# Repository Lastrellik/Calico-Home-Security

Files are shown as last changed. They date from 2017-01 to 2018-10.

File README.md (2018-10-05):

Calico Home Security
====================

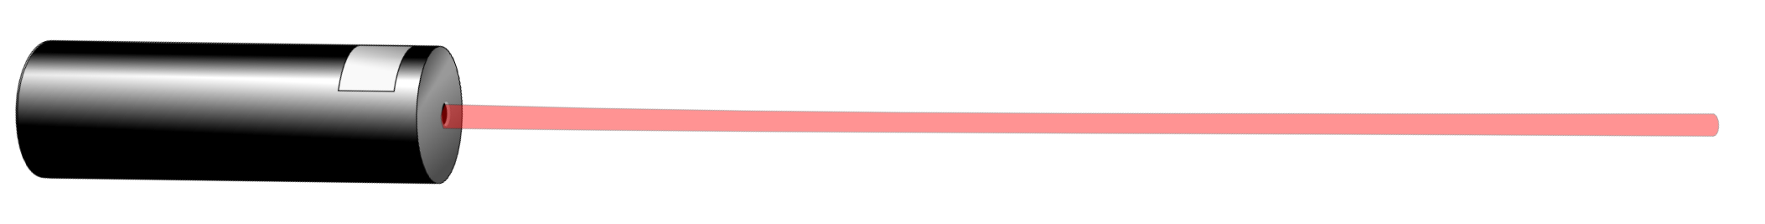
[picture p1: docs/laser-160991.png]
Laser Pointer

<sub>(_Image courtesy of [pixabay](https://pixabay.com/en/laser-optics-science-laser-pointer-160991/)_)</sub>

The **Calico Home Security System** is a home security platform to detect and react to intruders. It is an _extensible_ system with multiple _modules_ available to be added to it.

Table of Contents
=================

- [Documentation](#documentation)
  * [Hardware](#hardware)
- [Development](#development)
- [Wiring Diagrams / Schematics](#wiring-diagrams--schematics)
- [About the Project](#about-the-project)
  * [Authors](#authors)
  * [Background](#background)
  * [Why Calico?](#why-calico)

Documentation
=============

Hardware
--------

* [Arduino Uno](https://www.arduino.cc/en/Main/ArduinoBoardUno)
* Red Laser
* Photoresistor
* Piezo Buzzer
* A Few LEDs
* Various Wires and Miscellaneous Odds & Ends

Development
===========

* [IDE / Dev Environment Setup Instructions](./docs/development/dev_environment_setup.md)
* [Logging & Command Message Details](./docs/development/logging.md)
* [Future Development Ideas](./docs/development/future/future_ideas.md)

Wiring Diagrams / Schematics
============================

The wiring diagrams are all kept in the [docs](./docs/circuit_diagrams) directory.

Note that some modules will not function when other modules are present. Please refer to the table in the [Circuit Diagrams Readme](./docs/circuit_diagrams/README.md) for a compatibility chart.

* [BASE Module](./docs/circuit_diagrams/module_BASE/README.md)
* [WIFI Module](./docs/circuit_diagrams/module_WIFI/README.md)
* [Raspberry Pi w/Touchscreen Module](./docs/circuit_diagrams/module_PI/README.md)
* [TURRET Module](./docs/circuit_diagrams/module_TURRET/README.md)

About the Project
=================

Authors
-------

* [Christopher Nash](https://github.com/Zeustopher)
* [Tyler Jacobs](https://github.com/Boomstick105)
* [Dave Tille](https://github.com/sithboy)
* [Jason Bruderer](https://github.com/Lastrellik)

Background
----------

This project was created as an assignment for our CSIS 2810 Computer Architecture course.

The requirements for our project were that it must include a Micro Controller and it must be the foundation of the project. We chose to use an Arduino Uno for our project. The other requirement was that it must include at least one 'sensor' which reads in data and makes decisions based on that data.

Picture in your mind the classic movie scene where the good guy is trying to break into the vault of the bad guy to get back the master plans he has stolen. To get into the vault, the good guy must pass through a maze of laser trip wires without breaking a single beam or the alarm will sound!

We wanted to replicate those laser trip wires. We also wanted to have a well architected, well documented, and totally awesome project to be able to present to the class. Thus the **Calico Home Security System** was born!

Why Calico?
-----------

*Calico*, adj: Having sections or patches colored differently and usually brightly.

We wanted our system to be modular from the very beginning. Calico seemed a fitting name.

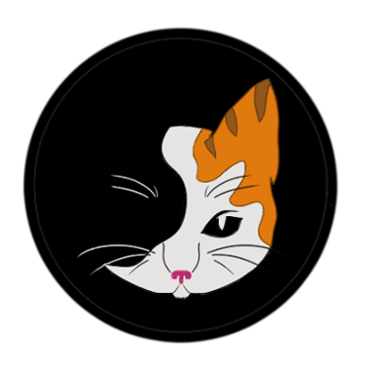
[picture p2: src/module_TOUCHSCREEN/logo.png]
Calico Logo


**Big or Small, Calico does it all.**

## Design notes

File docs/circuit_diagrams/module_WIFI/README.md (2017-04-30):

The WIFI Module
===============

The WIFI Module uses an [ESP8266](https://en.wikipedia.org/wiki/ESP8266) to add wireless functionality to the Calico Home Security System.
This wireless functionality allows you to be notified when the alarm is triggered.

* [Parts](#parts)
* [Bread Board Diagram](#bread-board-diagram)
* [Schematic Diagram](#schematic-diagram)
* [Setup Instructions](#setup)
* [Assembled Wifi Module](#assembled-wifi-module)
* [Future Development Ideas](#future-development-ideas)

Parts
-----
* **ESP8266 - ESP-01**
  - [Ebay](http://www.ebay.com/sch/i.html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): ~$5-7
    - Make sure you see where they are being shipped from. Many of these come from China so you'll be waiting weeks and weeks to get one...
  - [AliExpress](https://www.aliexpress.com/wholesale?catId=0&initiative_id=SB_20170302204802&SearchText=esp8266+esp-01): ~$1.50-2
    - If you are strapped for cash and have some time to wait to get them, you can buy them from sellers in China directly and save a few dollars.
  - Note that getting one with a "Breadboard Adapter" can be helpful for prototyping as the ESP-01 won't fit into a breadboard without it.
  - Also note that there are _many_ different models that contain as ESP8266 *(esp-01, esp-07, esp-12, esp-12E, esp-12F, NodeMCU, etc.)*. Make sure you purchase an "**ESP-01**" model. The ESP-01 model was a very commonly used one and had a small profile so I decided to go with it. In theory any of the other models would work as well though no instructions, wiring diagrams, or code are provided here.

Bread Board Diagram
-------------------
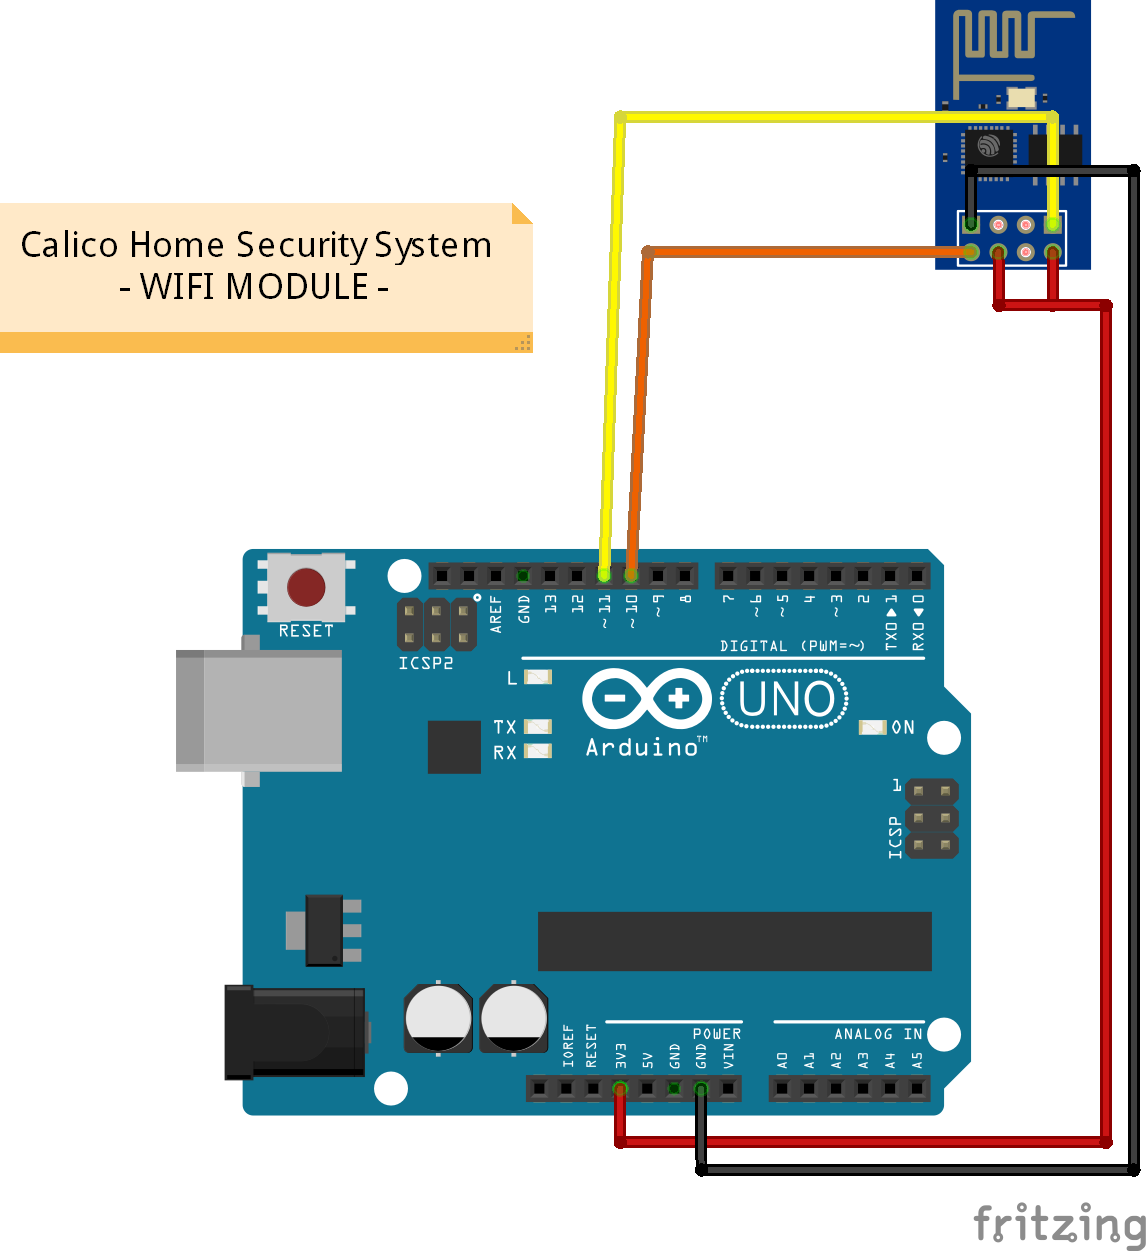
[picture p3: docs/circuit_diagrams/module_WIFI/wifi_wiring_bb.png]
WIFI Module Wiring Diagram

<sub>(_The WIFI Module Wiring Diagram for the Calico Home Security System_)</sub>

Schematic Diagram
-----------------
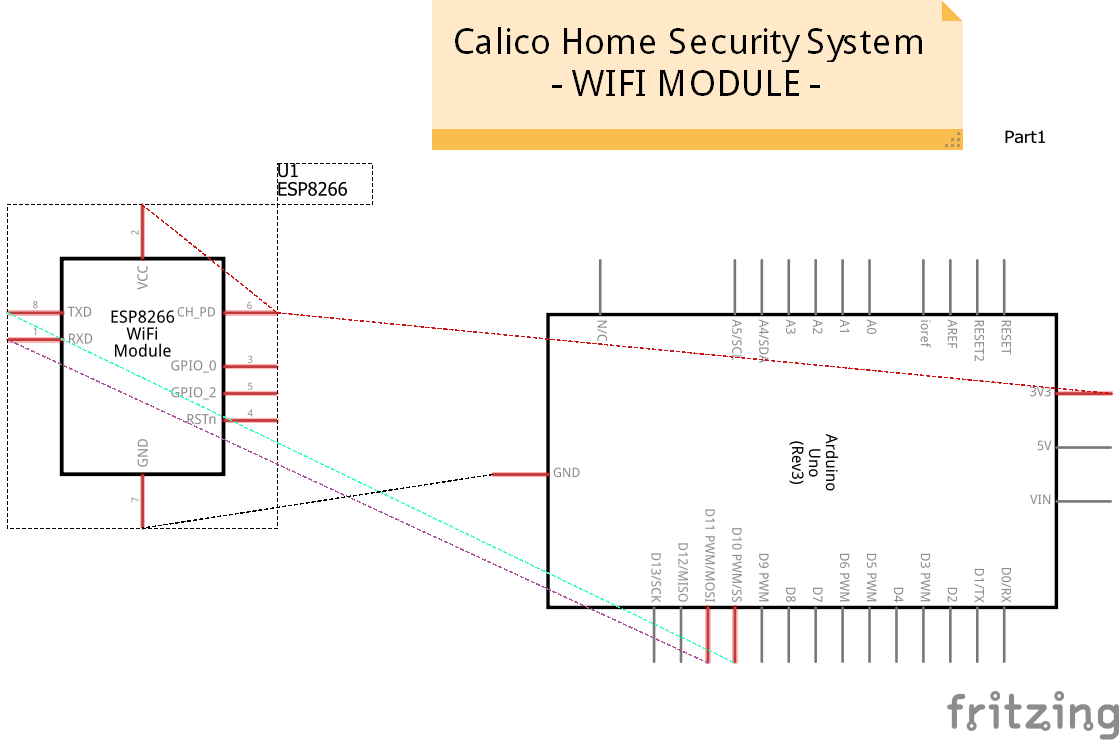
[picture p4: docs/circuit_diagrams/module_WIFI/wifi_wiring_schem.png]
WIFI Module Wiring Schematic

<sub>(_The WIFI Module Wiring Schematic for the Calico Home Security System_)</sub>

Assembled Wifi Module
---------------------
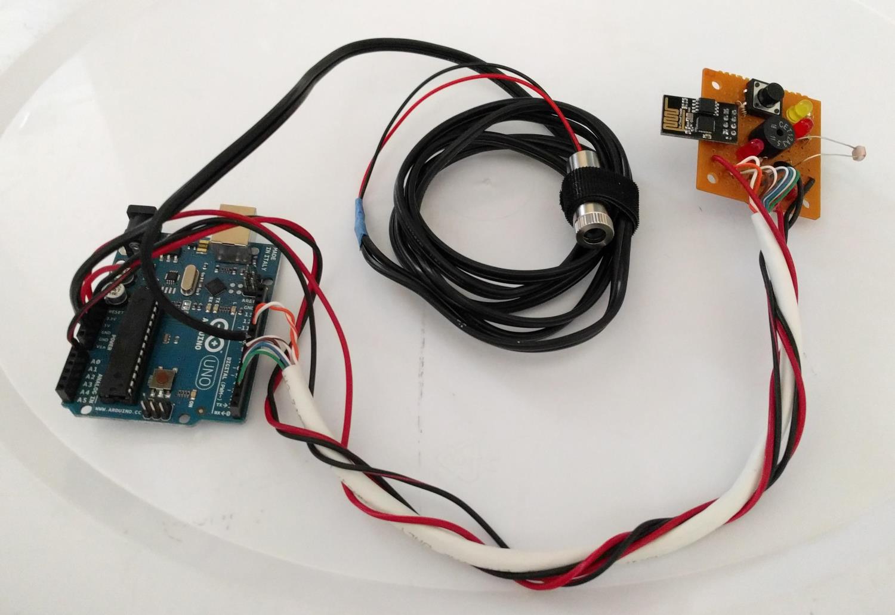
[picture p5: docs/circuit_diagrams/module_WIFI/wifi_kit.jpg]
Assembled Wifi Module

<sub>(_An assembled WIFI Module_)</sub>

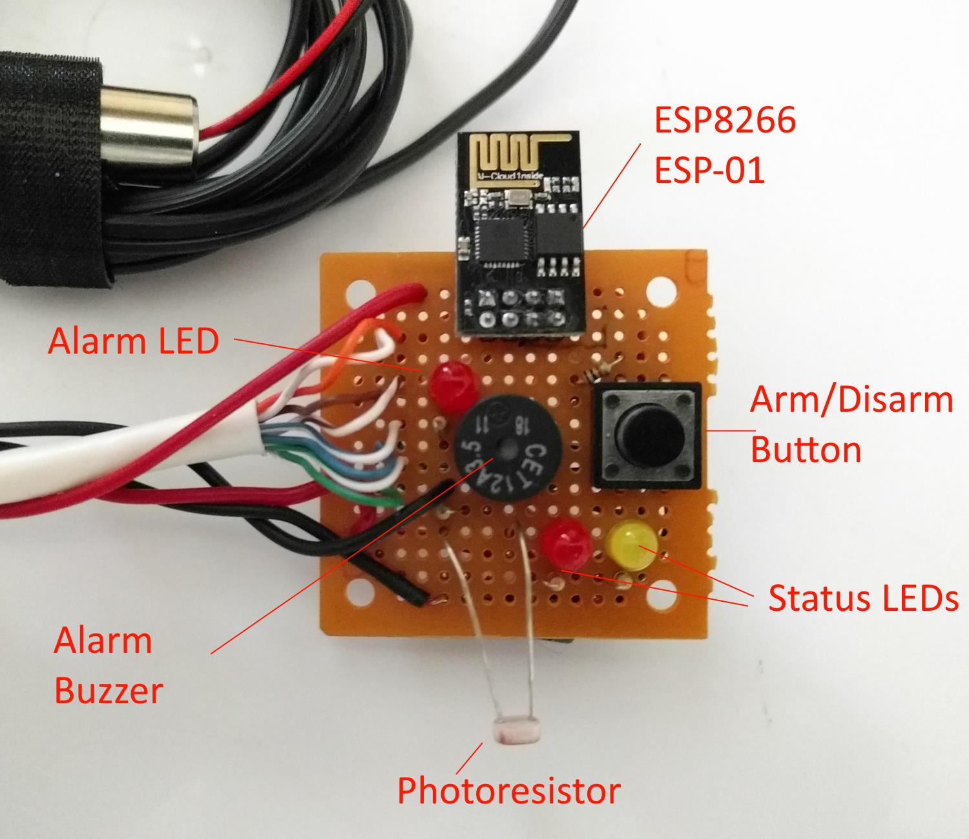
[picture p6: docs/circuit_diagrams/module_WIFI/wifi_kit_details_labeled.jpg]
Wifi Module Labeled

<sub>(_Labeled details of the assembled Wifi Module_)</sub>

Setup
=====
The **ESP8266** needs a few steps before it can be ready to communicate with the Arduino. You also need to create an **IFTTT** (*IF This Then That*) account and configure a **Maker** channel and create an IFTTT **Applet**.

Once you have followed all the steps in both the IFTTT and ESP8266 Setup sections, make sure you have configured your Wifi Settings within the [/src/Properties.cpp](https://github.com/Lastrellik/Calico-Home-Security/blob/master/src/Properties.cpp) file. There you will need to enable the Wifi Module and set your wireless SSID & Password as well as enter you IFTTT Key.

* [IFTTT Setup](#ifttt-setup)
* [ESP8266 Setup](#esp8266-setup)

Future Development Ideas
======================

Initially, the Wifi module is only able to notify you when the alarm is triggered. It is also using IFTTT for that notification. We opted to go this route because it had the fewest 'moving pieces' and made it so we didn't have to maintain any other infrastructure pieces ourselves.

However, there is no reason why there couldn't be the ability to take external commands in from the ESP8266 and have those control the alarm. A common framework/standard that people use with ESP8266's and connected them to the IoT is called [MQTT](http://mqtt.org/). Utilizing MQTT would involve setting up a broker service which you call with the ESP8266 to _publish_ events. The ESP8266 can also be configured to _pull_ events from the broker as well. In theory you could publish an event through some external means (an app, a website, etc.) into the MQTT broken with a message to "Arm" the alarm. The ESP8266 would _pull_ that message and then send a message to the Arduino Uno telling it to arm.

Another potential idea would be to integrate with Amazon's [AWS IoT Platform](https://aws.amazon.com/iot/). Even another idea would be to have the ESP8266 host a very simple RESTful API which you can hit directly from an external source.

The above would have taken much more time and resources to get fully set up than time for this project allowed. We opted to use the path of least resistance even though doing so limited the functionality we could include as part of this module.

IFTTT Setup
===========

You are going to need an account at [IFTTT](https://ifttt.com/). Create an account, verify your email address, etc. before continuing.

After you have created your IFTT account, install the IFTTT app on you cell phone. IFTTT has apps for both iOS and Android. Log in on your cell phone and go through the initial setup steps on your phone.

Once you have an account and have the app installed, you need to configure the Maker channel to be part of your IFTTT account. To do this, navigate to the [Maker channel](https://ifttt.com/maker) and activate it. Once you activate that channel you should be shown a screen which contains a link similar to `https://maker.ifttt.com/use/ABCDEFG`. Copy and paste that URL into your browser.

At the top of the screen in large letters there will be a banner which says something similar to `Your key is: ABCDEFG`. Copy this key and paste it into the Properties.cpp file.

Now we need to create an Applet in IFTTT.

1. Navigate to the [My Applets](https://ifttt.com/my_applets) page in IFTTT. We are going to need to create an applet for the `Maker` channel which will send a notification to our phone.
2. Click on the `New Applet` button.
3. Set the "This" to be the Maker channel.
4. Click on the `Receive a web request` box.
5. Set the Event Name to `alarm_tripped` _(Note that you can configure this to be something different if you'd like in the Properties.cpp file. Just make sure it matches what you type in here.)_.
6. Click the `Create Trigger` button.
7. Set the "That" to be the `Notifications` channel.
8. Click the `Send a notification` box.
9. Set the Notification to be `Your alarm HOME - FRONT DOOR was TRIGGERED on {{OccurredAt}}`  _(Note you can really set this to be whatever you want. This is just an example notification that you can tweak in the future to be whatever you like it to be.)_
10. Click the `Create Action` button.
11. Click the `Finish` button.

You are now configured to use IFTTT! Make sure you have included the key in the Properties.cpp file or your notifications sent when the alarm is triggered will not function.

**Want to have some additional fun?** See what other channels you can add an also trigger when an alarm is triggered. For example, you could have it send you a text. You could have it send you a tweet or post on your Facebook page. You could log every event in a Google Spreadsheet. You could have it turn on your Phillips Hue lights. You could... you get the idea. Welcome to the connected world of IFTTT!

IFTTT Notification
------------------

This is an example of the notification that is sent to your phone from the IFTTT service:

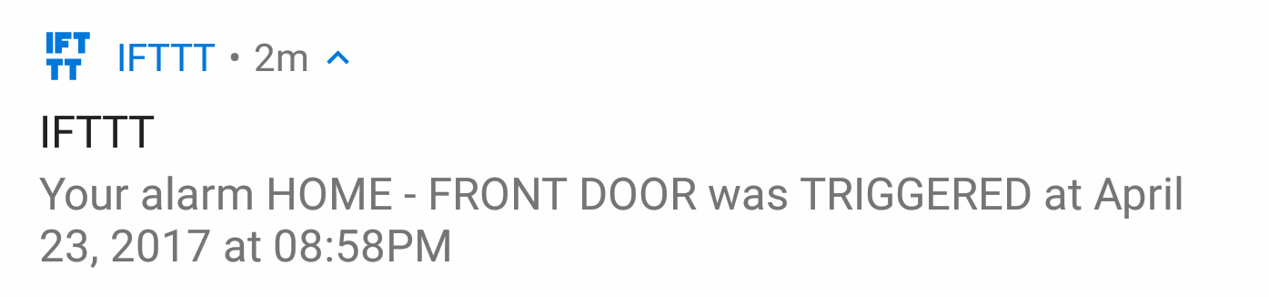
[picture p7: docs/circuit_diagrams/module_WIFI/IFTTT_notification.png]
IFTTT Notification Screenshot


ESP8266 Setup
============

Set ESP8266's Baud Rate to 9600
-------------------------------
By default, the ESP8266 communicates at `115200` baud which is too fast for the Arduino Uno to communicate with it using SoftwareSerial. We need to change that baud rate to `9600` which is the Arduino Uno's default baud rate. You only need follow these instructions once. This setting is persisted on the ESP-01.

1. Create a new project in PlatformIO. Call it something similar to "esp8266_setup"
2. Paste the following code into a `main.cpp` file

	```c++
	#include "Arduino.h"
	#include <SoftwareSerial.h>

	SoftwareSerial esp8266(10,11);

	void setup(){
	  Serial.begin(115200);
	  while (!Serial) { }
	  esp8266.begin(115200);
	}

	void loop(){
	  esp8266.listen();
	  if (esp8266.available() ) {
	    Serial.write(esp8266.read());
	  }

	  if (Serial.available() ){
	    esp8266.write(Serial.read());
	  }
	  delay(10);
	}
	```

3. Build then upload `main.cpp`
4. After the code has uploaded, launch the Terminal - make sure baud rate is set to `115200`
5. In the Terminal window, type `AT` and press Enter
  * _If you have issues with this step, try unplugging and plugging back in the Arduino and relaunching the Serial Monitor. Also try relaunching Atom. It appears that it sometimes just gets into a state where it doesn't fully recognize you are sending commands through it._
6. You should get back a message `OK`
7. In the Terminal window, type `AT+UART_DEF=9600,8,1,0,0` and press Enter
8. In the terminal window you should see the cursor moving and either blank or garbled characters will be displayed.
9. In the above code, change both instances of `115200` to `9600`
10. Build and upload this updated code
11. Relaunch the Terminal - make sure baud rate is set to `9600` this time
12. In the Terminal window, type `AT` and press Enter
13. You should get back a message `OK`
14. Your ESP8266 is now configured to communicate at 9600 baud. Continue on with making sure that the Arduino Uno and the ESP8266 can communicate with each other.

Make Sure Arduino and ESP8266 can communicate with each other
-------------------------------------------------------------

1. Paste the following code into a `main.cpp` file

	```c++
	#include "Arduino.h"
	#include <SoftwareSerial.h>

	SoftwareSerial esp8266(10,11);

	void setup() {
	  Serial.begin(9600);
	  esp8266.begin(9600);
	  delay(1000); // Let the module self-initialize
	}

	void loop() {
	  delay(5000);
	  Serial.println("Sending an AT command...");
	  esp8266.println("AT");
	  delay(100);
	  while (esp8266.available()){
	     String inData = esp8266.readStringUntil('\n');
	     Serial.println("Got response from ESP8266: " + inData);
	  }
	}
	```

2. Build then upload `main.cpp`
3. After the code has uploaded, launch the Terminal
4. You should see output like this every 5 seconds
	```
	Sending an AT command...
	Got response from ESP8266: AT
	Got response from ESP8266:
	Got response from ESP8266: OK
	```

5. Congratulations - your EPS8266 and your Arduino Uno are successfully communicating with each other! At this point you can go and upload the actual project's code to your Arduino.

In Case Of Emergency
-------------------

Long story... **Be careful what commands you send to the ESP8266**! Don't **EVER** run ~~`AT+IPR=9600`~~ !! This will brick your ESP8266 and you have to do a whole bunch of stuff to get it to work again including flashing a set of firmware to it... Even finding that firmware was a huge hassle. As such, just in case we need it again in the future, I've included the firmware here in the repository. In order to flash it you need to use a tool called `esptool.py`. I'm not going to give detailed instructions here on how to do it. Just be careful...

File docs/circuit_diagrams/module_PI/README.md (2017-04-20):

The Raspberry Pi Module
===============

The **Raspberry PI module** integrates a [Raspberry Pi 3](https://www.raspberrypi.org/products/raspberry-pi-3-model-b/) into the circuit to add another layer of functionality. It is installed by simply plugging a serial cable from any of the USB ports on the Raspberry Pi into the serial port on the Arduino Uno. It includes the following features:

* A 7'' Touchscreen to allow for a GUI
* A timestamped logging system
* A way to manage users and keycodes
* Email alerts with attachments
* SSH and VNC control
* USB webcam support
* A web interface

This module is set up to arm, disarm, calibrate, decalibrate and trigger through the GUI. When the alarm is armed and the laser is broken, the attached USB webcam takes a picture and sends it as an attachment to the recipients listed in the command line arguments (see below). It then goes into a "tripped" state where it plays a waiting noise for 30 seconds while it waits for potential intruder to disarm the alarm. If it is not disarmed in the given time, it will "trigger" and sound the alarm while taking another picture to send as an email attachment. The alarm will sound until it is disarmed. All actions are logged in a log file called *PI_LOG.txt* and pictures are stored in the folder *PI_PICS* as jpg files.

Parts
-----
* [Raspberry Pi 3 Model B](https://www.raspberrypi.org/products/raspberry-pi-3-model-b/)  
  -[This kit](https://www.amazon.com/LoveRPi-Raspberry-Plug-Play-Starter/dp/B01IYBZEV6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) comes with all the hardware you need to get started.
* [7 Inch Touchscreen](https://www.amazon.com/Raspberry-Pi-7-Touchscreen-Display/dp/B0153R2A9I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)
* [Raspberry Pi Touchscreen Case](https://www.amazon.com/Case-Official-Raspberry-Touchscreen-Display/dp/B01HV97F64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)
* [USB webcam](https://www.amazon.com/Logitech-Widescreen-Calling-Recording-Desktop/dp/B006JH8T3S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)

Raspberry Pi Setup
=====
To avoid wasting resources on the Raspberry Pi, the operating system has been built up from scratch starting with [Raspbian Jessie Lite](https://www.raspberrypi.org/downloads/raspbian/). Rasbian Lite is a Linux operating system built specifically for the Raspberry Pi and has no extra programs installed, not even a GUI, which will be installed later. Raspbian Jessie is installed by following these steps:

* [Download](https://www.raspberrypi.org/downloads/raspbian/) Raspbian Jessie Lite and burn it to an SD Card. Step by step instructions with download liks to all necessary tools are found [here](https://www.raspberrypi.org/documentation/installation/installing-images/README.md).
* Insert the SD card into the Raspberry PI and connect it to a monitor with an HDMI cable. Then connect a keyboard, mouse, webcam and power cable to the Pi.
* Once the Raspberry Pi boots up, log in with the username "pi" and password "raspberry".
* Create the "calico" and the "developer" user with the commands ```sudo adduser calico``` and ```sudo adduser developer```. When prompted, enter in the desired password and optionally add details when asked.
* Add the "developer" account to the suders group with the command ```sudo usermod -a -G sudo developer```.
* Switch over to the developer account with the command ```sudo su developer``` and enter in the developer password set up for that user account earlier.
* Remove the "pi" user with the command ```sudo userdel pi``` and delete the pi home folder with ```sudo rm -rf /home/pi```.
* For initial configuration, we'll need to expand the filesystem by going into the Raspberry Pi configuration menu with the command ```sudo raspi-config```. 
* Select the option to **Expand Filesystem** to expand the file system to the entire SD card. Reboot the Pi when asked.
* After rebooting, log into the Pi using the developer account and connect the Pi to WiFi by following [this guide](https://learn.adafruit.com/adafruits-raspberry-pi-lesson-3-network-setup/setting-up-wifi-with-occidentalis).
* Once connected to the network, update the Raspberry Pi software with the command ```sudo apt-get update && sudo apt-get upgrade -y && sudo reboot```
* Log into the Pi again and set up the appropriate language, regional setting and keyboard layout for your particular case with the command ```sudo raspi-config``` and selecting #5, "Internationalization Options".
* Next, install the [PIXEL](https://www.raspberrypi.org/blog/introducing-pixel/) shell with the following commands: 
```
sudo apt-get install --no-install-recommends xserver-xorg
sudo apt-get install raspberrypi-ui-mods
sudo apt-get install lightdm
```
if ever asked, be sure to install all dependencies.
* Reboot the Pi with ```sudo reboot``` and log in as the developer again, but this time using the gui.
* Open up a terminal window with ctrl+alt+t and go back into the Raspberry Pi configuration menu with ```sudo raspi-config``` and install VNC by navigating to **Interfacing Options** and selecting **VNC** and then choosing **Yes**. You can find more information on setting up and controlling the Raspberry Pi through VNC [here](https://www.raspberrypi.org/documentation/remote-access/vnc/).
* Next, install and enable open-ssh server through the same method as the previous step, but with **SSH** instead of **VNC**. More information on installing and controlling the Raspberry Pi via SSH can be found [here](http://www.instructables.com/id/Use-ssh-to-talk-with-your-Raspberry-Pi/)
* Install Maven with the command ```sudo apt-get install maven```
* Install git with the command ```sudo apt-get install git```
* Install Java with these commands:
```
sudo apt-add-repository ppa:webupd8team/java
sudo apt-get update
sudo apt-get install oracle-java8-installer
```
* Insure Java is installed with ```javac -version```

## Touchscreen and Case Installation
The security system is equipped with a [Touchscreen](https://www.amazon.com/Case-Official-Raspberry-Touchscreen-Display/dp/B01HV97F64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) and encapsulated in a [Case](https://www.amazon.com/Case-Official-Raspberry-Touchscreen-Display/dp/B01HV97F64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) in order to maximize convenience. Installation instructions for the Touchscreen can be found [here](https://thepihut.com/blogs/raspberry-pi-tutorials/45295044-raspberry-pi-7-touch-screen-assembly-guide) and installation instructions for the case can be found [here](https://smarticase.com/products/smartipi-touch). A power adapter for the Pi and the Touchscreen is included with the case.

To install the whole module, simply mount the touchscreen into the case by screwing it into the assembly and run the included ribbon cable into the monitor port in the Raspberry Pi. No additionaly drivers or configuration is required for the touchscreen. A more detailed set of instructions for connecting the Raspberry Pi to the touchscreen can be found [here](https://thepihut.com/blogs/raspberry-pi-tutorials/45295044-raspberry-pi-7-touch-screen-assembly-guide). 

Development
============
In order for the Raspberry Pi to communicate with the Arduino through Serial, add the *developer* and *calico* users to the uucp, dialout, lock and tty groups according to [this guide](https://github.com/Fazecast/jSerialComm/wiki/Installation) from JSerialComm. Installation of Calico Home Security from the [official GitHub repository](https://github.com/Lastrellik/Calico-Home-Security) is accomplished on the Raspberry Pi by the following steps:
* Log in to the Raspberry Pi's GUI using the developer credentials.
* In the terminal, switch to the developer account with the command ```cd ~```
* Clone the GitHub repository with ```git clone https://github.com/Lastrellik/Calico-Home-Security.git```
* For security purposes, change the Linux permissions on all files in the **Calico Home Security** with the command ```chmod 700 ~/Calico-Home-Security/```
* Plug in the [Base Module](https://github.com/Lastrellik/Calico-Home-Security/tree/master/docs/circuit_diagrams/module_BASE) to a USB port on the Raspberry Pi.

## Running Calico Home Security
The JUnit tests on the Raspberry Pi are fully dependent on both the USB webcam and the Arduino Uno being plugged in to the Raspberry Pi. Running the program is currently accomplished by running the command ```mvn exec:java -Dexec.mainClass="module_PI.Raspberry_PI.main.PiApp" -Dexec.args="<sending gmail address> <sending account password> <all recepient email addresses separated by a space>"``` where **sending gmail address** is the email address the alert emails will be sending from, **sending account password** is the password of that Gmail account.

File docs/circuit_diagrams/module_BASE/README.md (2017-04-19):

The BASE Module
===============

The BASE module is the _foundation_ for the entire Calico Home Security System.

Setup
-----

No specific setup is required for the BASE Module other than assembly the components and uploading the main project code.

For other Modules you'll be required to add additional physical components as well as modify the [/src/Properties.cpp](https://github.com/Lastrellik/Calico-Home-Security/blob/master/src/Properties.cpp) file to enable the various installed Modules.

Hardware
--------

* Arduino Uno
* Photoresistor
* 3-5V, 5mW Red Laser
* Piezo Buzzer
* Push Button
* 5x 10k ohm Resistors
* 2x Red LEDs
* Green LED

Bread Board Diagram
-------------------

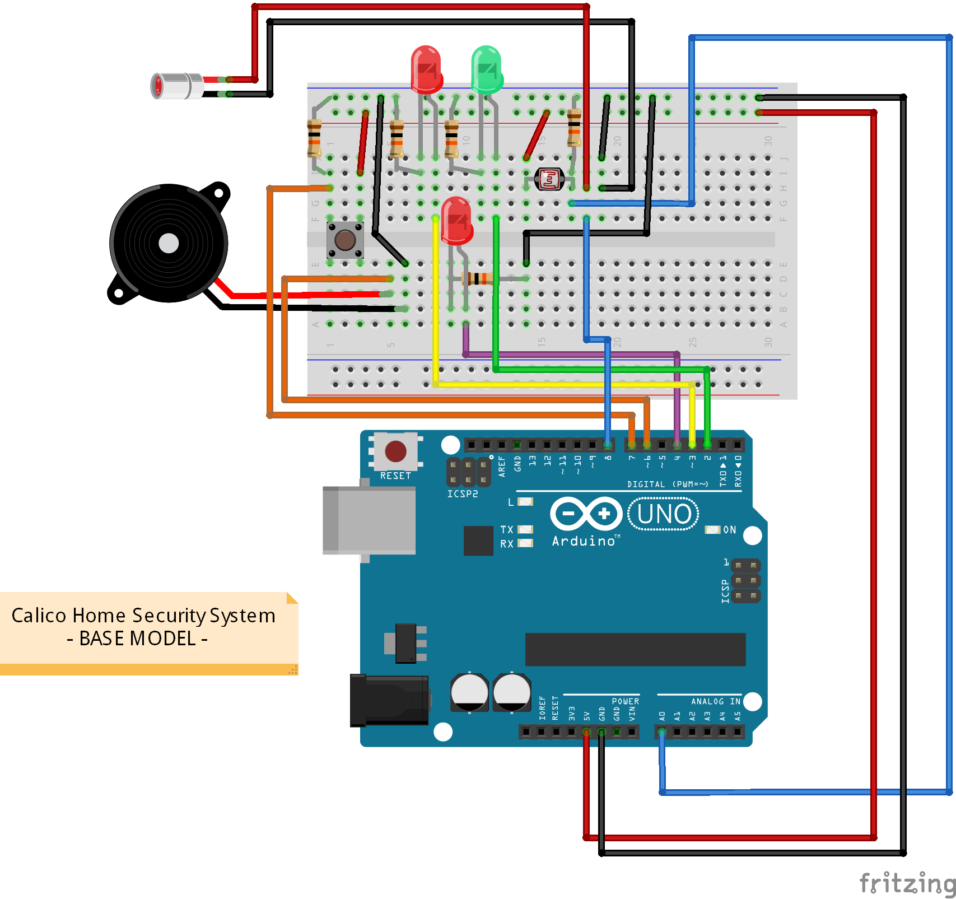
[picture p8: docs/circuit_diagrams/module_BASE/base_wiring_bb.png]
Base Wiring Diagram

<sub>(_The Base Wiring Diagram for the Calico Home Security System_)</sub>

Schematic Diagram
-----------------

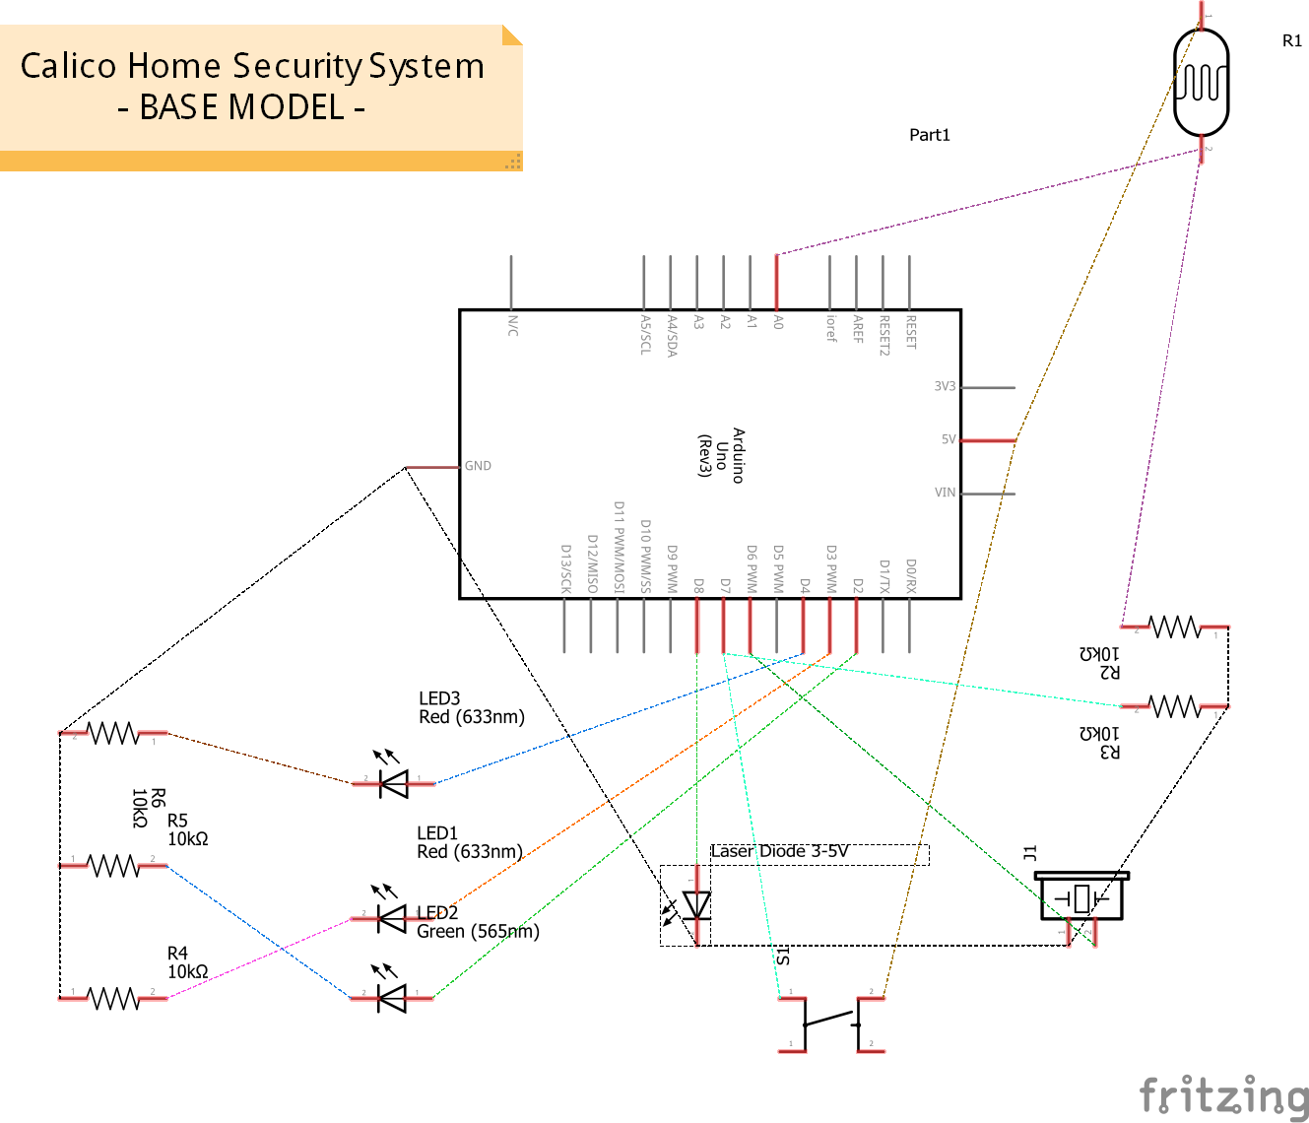
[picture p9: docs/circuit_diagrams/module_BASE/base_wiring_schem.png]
Base Wiring Schematic

<sub>(_The Base Wiring Schematic for the Calico Home Security System_)</sub>

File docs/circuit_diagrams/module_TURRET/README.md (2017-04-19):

The TURRET Module
=================

The TURRET Module allows the Calico Home Security System to **fight back**! The TURRET Module adds a _fully-automated_ gun (airsoft) turret. Because of the complexities of controlling a fully-automated gun turret, an additional dedicated Arduino Uno is used to control the functionality of the turret. The Base Module's Arduino Uno communicates with the Turret's Arduino Uno through a protocol called I2C.

Parts
-----
* Additional Arduino Uno
* 2x Servos
* [4-Relay Module](https://www.amazon.com/Elegoo-Channel-Optocoupler-Arduino-Raspberry/dp/B01HEQF5HU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)

Bread Board Diagram
-------------------

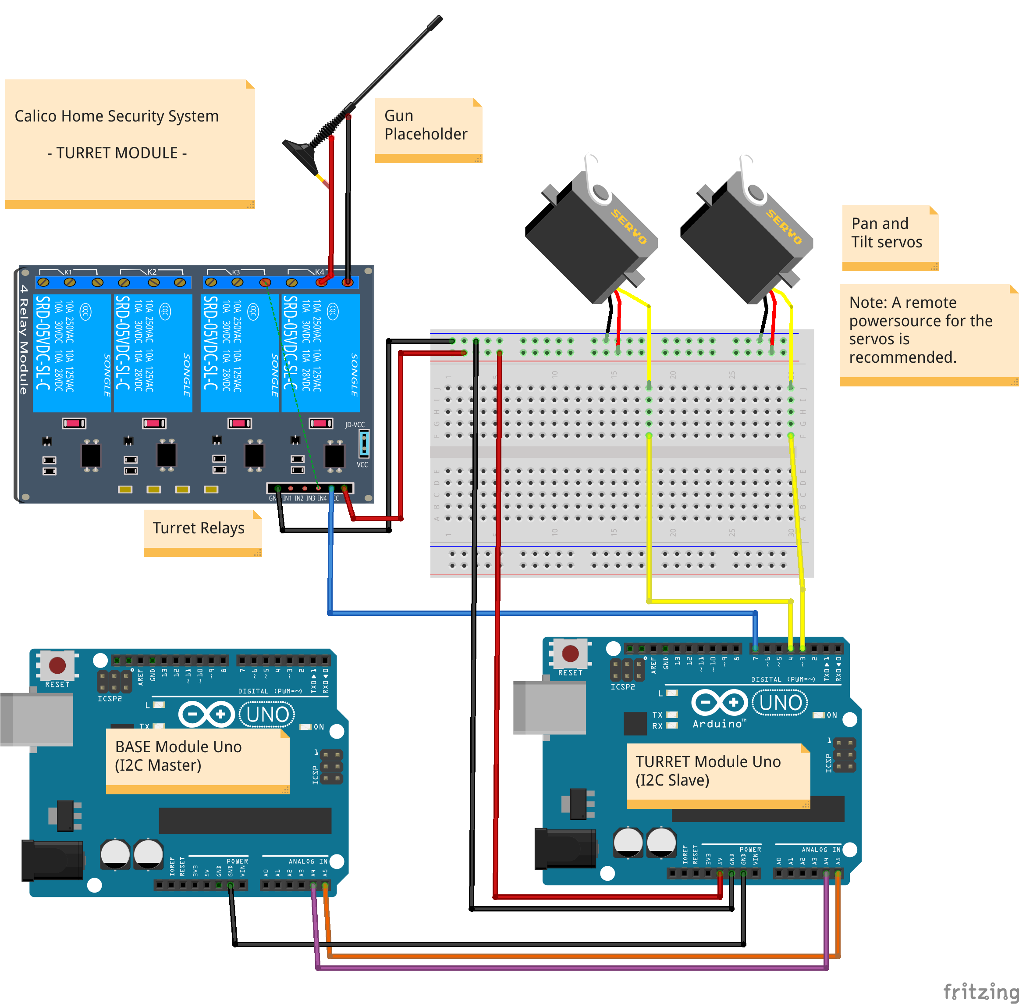
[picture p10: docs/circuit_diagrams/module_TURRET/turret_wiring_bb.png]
TURRET Module Wiring Diagram

<sub>(_The TURRET Module Wiring Diagram for the Calico Home Security System_)</sub>

Schematic Diagram
-----------------

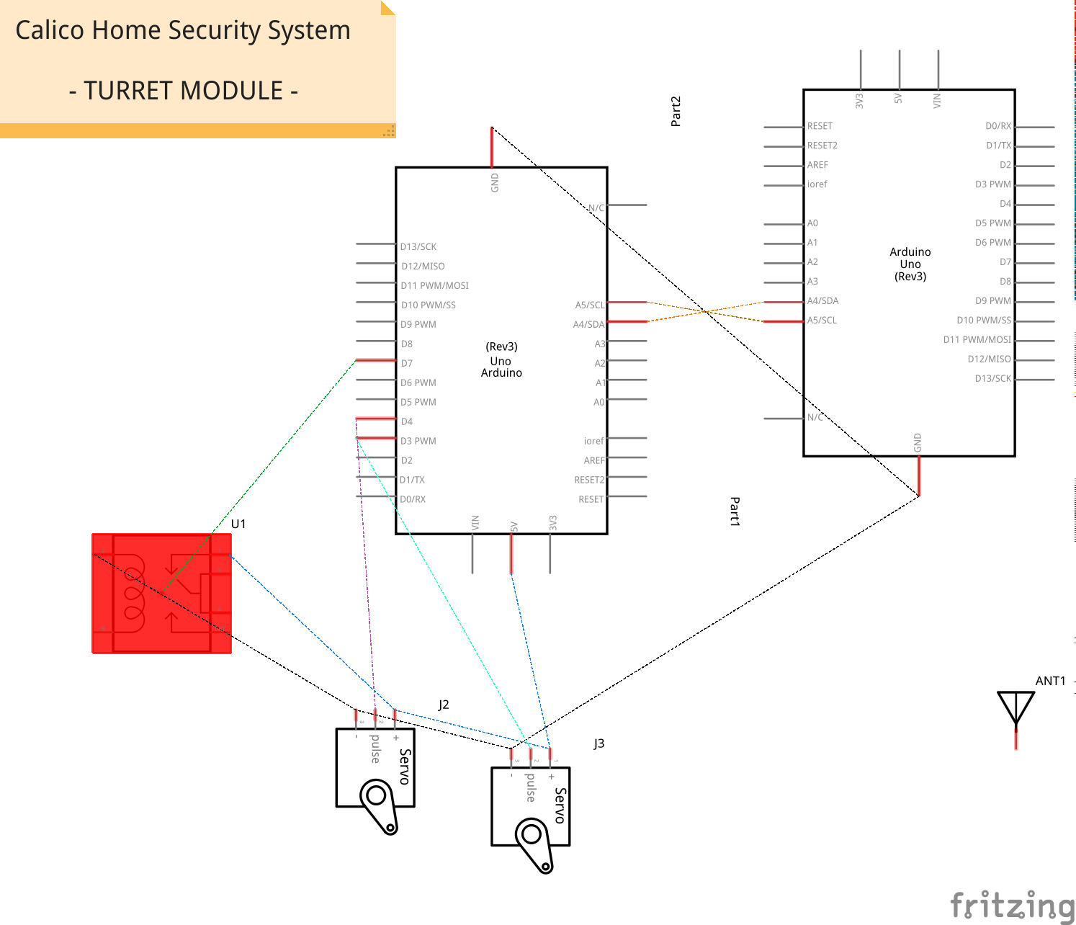
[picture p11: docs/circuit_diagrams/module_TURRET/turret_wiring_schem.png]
TURRET Module Wiring Diagram

<sub>(_The TURRET Module Wiring Diagram for the Calico Home Security System_)</sub>

I2C Protocol
------------
I2C stands for Inter-Integrated Circuit. Many details can be read online to learn about I2C in great detail. Some example links are [Wikipedia](https://en.wikipedia.org/wiki/I%C2%B2C) and [Sparkfun](https://learn.sparkfun.com/tutorials/i2c). The bare minimum you need to know is that this is a standard protocol created in order to allow low-power, low-speed communication between two microcontrollers.

Setup
=====

The Slave Arduino needs to have the contents of the `TurretSLAVE.cpp` file loaded onto it. There are multiple ways to do this. The easiest is to open that file in PlatformIO, copy the entire contents, paste them over top `main.cpp`, the deploy it to the Slave Arduino.

See It In Action
================

Take a look at the Turret Module doing a very basic sweep attack after the alarm has been triggered: https://youtu.be/5av2dN1TxHc

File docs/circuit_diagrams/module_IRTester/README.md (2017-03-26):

Fritzing Circuit Diagrams
=========================

This is a diagram of the testing module for the IR sensor and remote. The purpose of this module is to print the output of the IR remote so that specifically mapped buttons on the remote may be implemented in the base project. The remote will be used as an arming button to replace the analogue button currently implemented.

The sensor used has a 3 pin configuration. The (G) pin is used as ground, the (R) pin is used for power and plugged into the 5 volt port and the (Y) pin is used as the sensor and in this instance, run to the 11th digital pin. The Y pin returns the values of specific buttons used on the remote.

Please consult manufacturer specifications for your specific pin-layout.

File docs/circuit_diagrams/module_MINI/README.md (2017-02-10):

The MINI Module
===============

The MINI module is a trimmed down version of the BASE module. It functions with minimal components and is completely silent. It utilizes the Arduino's built-in LED to alert when the system has been tripped.

Hardware
--------

* Arduino Uno
* Photoresistor

Bread Board Diagram
-------------------

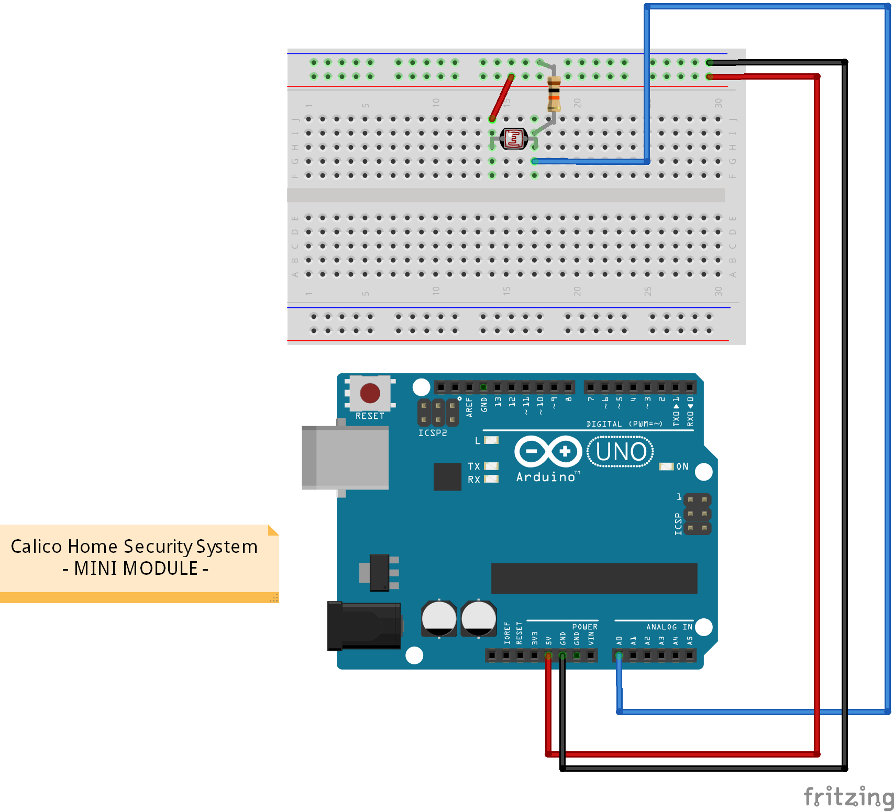
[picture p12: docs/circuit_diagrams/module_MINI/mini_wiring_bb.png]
Mini Wiring Diagram

<sub>(_The Mini Wiring Diagram for the Calico Home Security System_)</sub>

Schematic Diagram
-----------------

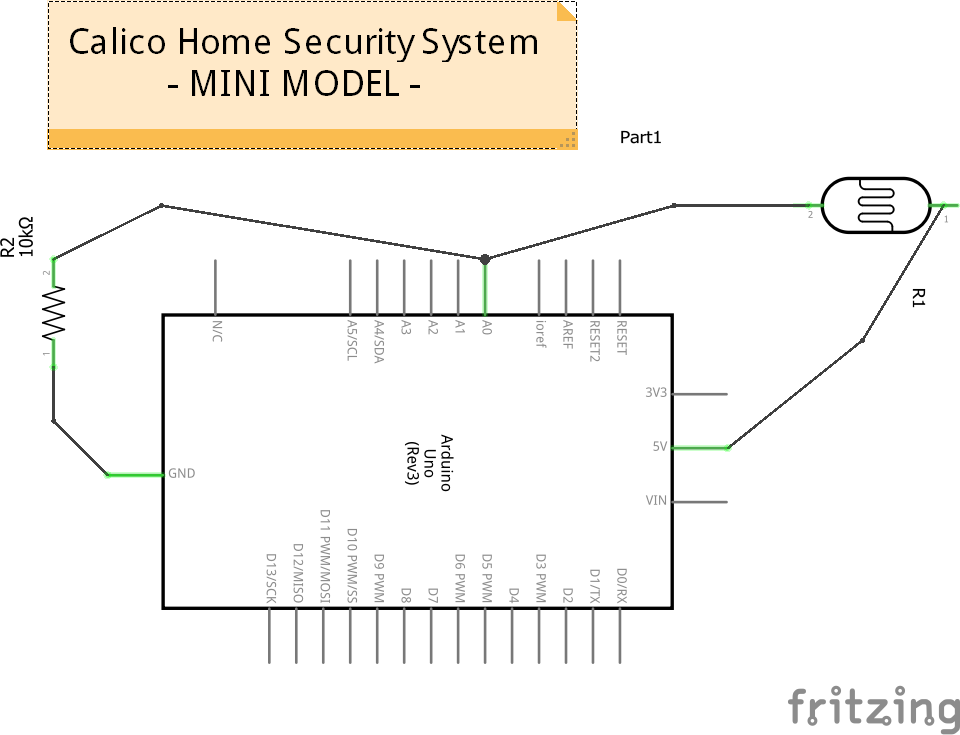
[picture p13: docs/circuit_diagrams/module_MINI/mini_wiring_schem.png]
Mini Wiring Schematic

<sub>(_The Mini Wiring Schematic for the Calico Home Security System_)</sub>

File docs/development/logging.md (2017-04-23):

Logging & Command Messages
==========================
This document describes the Logging & Command Message structure and usage.

Message Scheme
--------------
The scheme we decided on is similar to that of HTML codes. HTML codes follow a standard form with 3 digits. For example, `404` is a `Not Found` error. The first digit `4` represents a 'class' of error. In this case, a `Client Error`. The last two digits represents the actual 'message'.

Following a similar pattern we decided that the key things we needed to specify were a `Type`, a `Log Level`, and then the `Details` of the message. We will represent this with a 5-Digit number.

| Type | Log Level | Details |
| ---- | --- | --- |
| The `Type` of message such as a `Log` or a `Command` | Only applicable for `Log` commands. `Error`, ` Debug`, etc. | The nitty-gritty details on which message you are intending to send. |

The receiving client will be responsible for parsing the sent message and acting on it accordingly. Some ideas for accomplishing this might be to turn it into a String and looking at each character. Or an array list of Chars. Etc.

The Arduino will also receive commands using this same scheme. It will receive the message and respond. The Arduino's functionality will be limited in the actions it will perform. For example, if a client were to send the Arduino a Log message, the Arduino would just ignore the message as it would only be listening for a `Command` type of message.

Examples
--------
The following are a few examples of some messages which might be sent and what they translate to:
* `13514` = This message would represent a `1 - Log` Type command being logged at a `Debug` Log Level and the representing the `514` Detailed message (whatever `514` is defined as below).
* `30025` = This message would represent a `3 - Data` Type command. Since this is not a `Log` Type of command, the `Log Level` is irrelevant and thus a `0 - N/A` is given. The Details for this command are `025`. The intention is for you, the receiver, to execute this command. Perhaps it is meant to represent a command such as `Arm` or `Disarm`.

Developer Code Comment Convention
---------------------------------
Whenever a message is sent, it should have the code's translation included on the same line where the code is being sent. This will enable an easier time for other developers coming in at a future date and being able to more easily parse what is going on with the message being sent.

Example:
```c++
Serial.write(13514);  // 13514 = Log, Debug, Component Configured on Pin 14
```
This should hold true for both the Java and the C++ sides of the code.

Where possible, especially in Java, a value should be defined as a member variable with a descriptive name OR be 'built' using enum (or similar) values, all with descriptive names, so that the code can easily be translated by another developer.

Message Translation Chart
-------------------------
| Type [0-9]  | Log Level  [0-9] | Details  [000-999]  |
| --- | --- | --- |
| 0 - N/A | 0 - N/A | 000 - N/A |
| 1 - Log | 1 - Error | 001 - Execute Command: Arm |
| 2 - Data | 2 - Warn | 002 - Execute Command: Disarm |
| 3 - Command | 3 - Debug | 003 - Execute Command: Silence |
| 4 - Error | 4 - Info | 004 - Execute Command: Calibrate |
| 5 - Request | 5 - Trace | 005 - Execute Command: Trigger |
| | | 006 - Execute Command: Reset Calibration |
| | | 007 - Execute Command: Test Components |
| | | 008 - Execute Command: Trip|
| | | 009 - Execute Command: Toggle Laser |
| | | 100 - Alarm object successfully created |
| | | 101 - Alarm base photoresistor reading determined
| | | 102 - Alarm failed action
| | | 103 - Alarm successful action
| | | 104 - Alarm failed to arm
| | | 105 - Alarm successfully armed
| | | 106 - Alarm successful calibration
| | | 107 - Alarm has begun arming
| | | 108 - Alarm has been triggered
| | | 109 - Alarm calibration is being reset
| | | 110 - Alarm is being disarmed
| | | 111 - Alarm is being is being silenced
| | | 112 - Alarm has been tripped
| | | 150 - Button object successfully created
| | | 151 - Button has been pressed
| | | 200 - Buzzer object has been created
| | | 201 - Buzzer has started to sound
| | | 202 - Buzzer has stopped sounding
| | | 250 - Component object successfully created
| | | 300 - ComponentTester default constructor called
| | | 301 - ComponentTester object successfully created
| | | 350 - Laser object successfully created
| | | 351 - Laser has been turned on
| | | 352 - Laser has been turned off
| | | 353 - Laser has been toggled
| | | 400 - LED object successfully created
| | | 401 - LED has been turned on
| | | 402 - LED has been turned off
| | | 404 - LED toggling
| | | 450 - Photoresistor object has been successfully created

**Details Block Definitions:**
* [001 - 009] - Reserved for Commands intended for the Alarm (Arduino) to execute.
* [100 - 149] - Reserved for Alarm Class messages to be logged.
* [150 - 199] - Reserved for Button messages to be logged.
* [200 - 249] - Reserved for Buzzer messages to be logged.
* [250 - 299] - Reserved for Component messages to be logged.
* [300 - 349] - Reserved for ComponentTester messages to be logged.
* [350 - 399] - Reserved for Laser messages to be logged.
* [400 - 449] - Reserved for LED messages to be logged.
* [450 - 499] - Reserved for Photoresistor messages to be logged.
* [700 - 999] - Currently reserved for TURRET Commands.

**Notes:**
* In general, you should never send a message of Type `0`. That really just wouldn't make any sense...
* `Log Level` is only relevant when a `Log` Type message is sent. In all other cases a `0 - N/A` should be passed.

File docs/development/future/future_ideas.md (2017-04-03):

# Future Ideas

This page contains various ideas for future development of the Calico Home Security System.

* [Fully Decentralized Cloud-based Alarm Management](#fully-decentralized-cloud-based-alarm-management)
* [Web-based Control Application](#web-based-control-application)

## Fully Decentralized Cloud-based Alarm Management

Utilize MQTT to decentralize all functionality, alarming, logging, and remote control.

### What is MQTT?

"[MQTT](http://mqtt.org/) is a machine-to-machine/"Internet of Things" connectivity protocol. It was designed as an extremely lightweight publish/subscribe messaging transport." It provides a mechanism for a Publisher to push information to a specific _topic_ and for that message to be forwarded to any Subscriber who is listening to that topic. The concepts behind a publish/subscribe system are out of the scope of this document but _lots_ of information can be gained from all over the internet about it.

#### - Self Hosted MQTT Options
The advantage of self-hosting is that you are entirely in control of every aspect of the MQTT topics, data, etc. The disadvantage is you have to manage your own infrastructure.
* [Mosquitto](https://mosquitto.org/)

#### - Cloud MQTT Options
The advantage of a cloud MQTT broker is that you don't have to manage your own infrastructure. The disadvantage is that they can be costly to use. Both of the below options offer a free version that is limited in the number of hosts (publishers & subscribers) you can have as well as the number of messages you can process.
* [CloudMQTT](https://www.cloudmqtt.com/)
* [HiveMQ](http://www.hivemq.com/)

### High-level Diagram

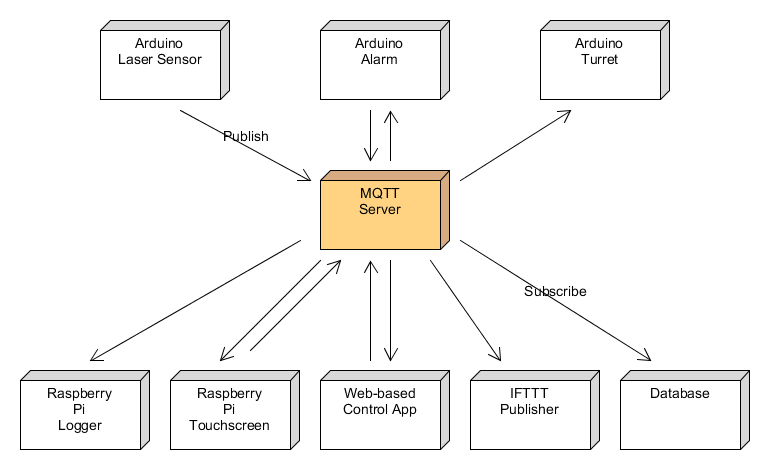
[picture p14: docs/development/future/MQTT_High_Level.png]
MQTT High Level


<sub>(_This diagram was made using [UMLet](http://www.umlet.com/). The raw diagram is included in this directory for future modifications._)</sub>

### High-level Idea

The idea would be that each piece of the alarm system was standalone and was a Publisher and/or a Subscriber to various 'topics' that relate to the Alarm system. All of this could be accomplished through the use of Wifi (either built-in, ESP8266, etc.). Let me illustrate with a small narrative based on the above diagram.

The laser sensor could be running remotely on an Arduino all of its own and just constantly publishing messages to MQTT with its current status or possibly just publish when the laser line is tripped.

The Alarm could then be running on another Arduino that had a buzzer, some lights, a siren, etc. When the message is published by the laser sensor Arduino, the Alarm, who was subscribed to the topic the sensor posted to, would get a message pushed to it letting it know the laser was tripped. It could then act accordingly.

At the same time that the Alarm received the above message, the turret, also running on its own Arduino and subscribed to the same topic, received the message and has started reacting to it by looking for the perp to take him out.

Also at the same time the Raspberry Pi received the same message and has logged that it happened at the same time that the Touchscreen has changed to show a red flashing message about it being tripped. Since the Touchscreen is also a publisher, the person who tripped the laser line deactivated things via the touchscreen and his personal pin. This publishes a message to a different topic which the Alarm is subscribed to and the alarm stops sounding. This deactivation is logged to the Pi as well as written to a persistent database that keeps track of the last time that user has logged in.

So - the essence of the above narrative is that each piece works on its own and using MQTT you can asynchronously 'trigger' a whole bunch of things to happen from publishing a single message to MQTT that others can subscribe to.

## Web-based Control Application

A Web Application that is accessible from anywhere that you could see the status, arm/disarm the system, and silence a triggered alarm.

It could utilize the above MQTT strategy to publish a message that the alarm, etc. are subscribed to. Some ideas for this could be a SPA (Single Page Application) written in Angular or React. Or it could be a full-fledge web application backed by Java using SpringBoot. Maybe even both and just make it a [JHipster](https://jhipster.github.io/) application. It would need some sort of user storage probably in a database so that a user had to authenticate before it would allow you to access the system.

An anywhere-accessible web application is one of the big things in the IoT right now. The idea that you can turn you heater up from anywhere or see who is ringing your doorbell while sitting at lunch in Paris is basically a must have feature for a connected device. Adding something like this to the system would be a big benefit.

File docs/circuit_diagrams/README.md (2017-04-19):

Fritzing Circuit Diagrams
=========================

This directory holds circuit and wiring diagrams created using [Fritzing]([http://fritzing.org/home/).

Detailed installation instructions are not included in this documentation. We are using a standard installation of Fritzing.

Each _Module_'s diagrams are organized into its own folder.

Module Compatibility Chart
--------------------------
Not all modules are compatible with eachother. The following chart shows those which will work with eachother.

| | Mini | Base | Pi | Wifi | Touchscreen | Turret |
|---|---|---|---|---|---|---|
| Mini | :white_check_mark: | :x: | :white_check_mark: | :white_check_mark: | :white_check_mark: | :white_check_mark: |
| Base | :x: | :white_check_mark: | :white_check_mark: | :white_check_mark: | :white_check_mark: | :white_check_mark: |
| Pi | :white_check_mark: | :white_check_mark: | :white_check_mark: | :x: | :white_check_mark: | :white_check_mark: |
| Wifi | :white_check_mark: | :white_check_mark: | :x: | :white_check_mark: | :x: | :white_check_mark: |
| Touchscreen | :white_check_mark: | :white_check_mark: | :white_check_mark: | :x: | :white_check_mark: | :white_check_mark: |
| Turret | :white_check_mark: | :white_check_mark: | :white_check_mark: | :white_check_mark: | :white_check_mark: | :white_check_mark: |

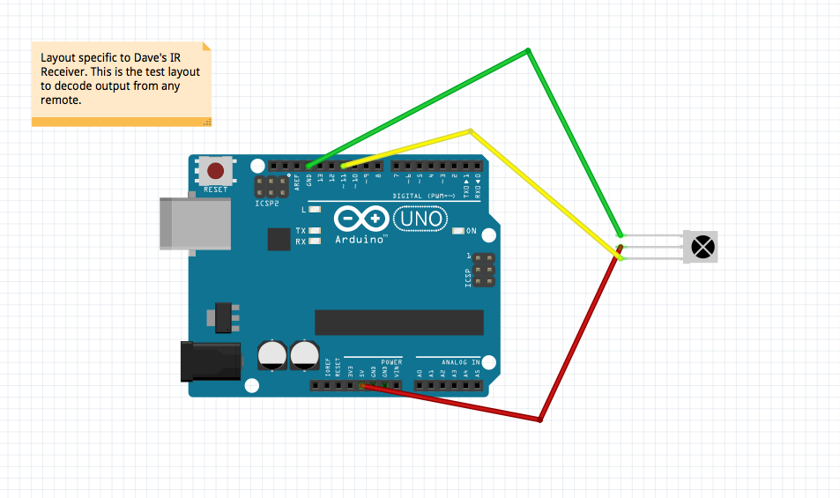
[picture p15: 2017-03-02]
docs/circuit_diagrams/module_IRTester/IRTest_Module.png

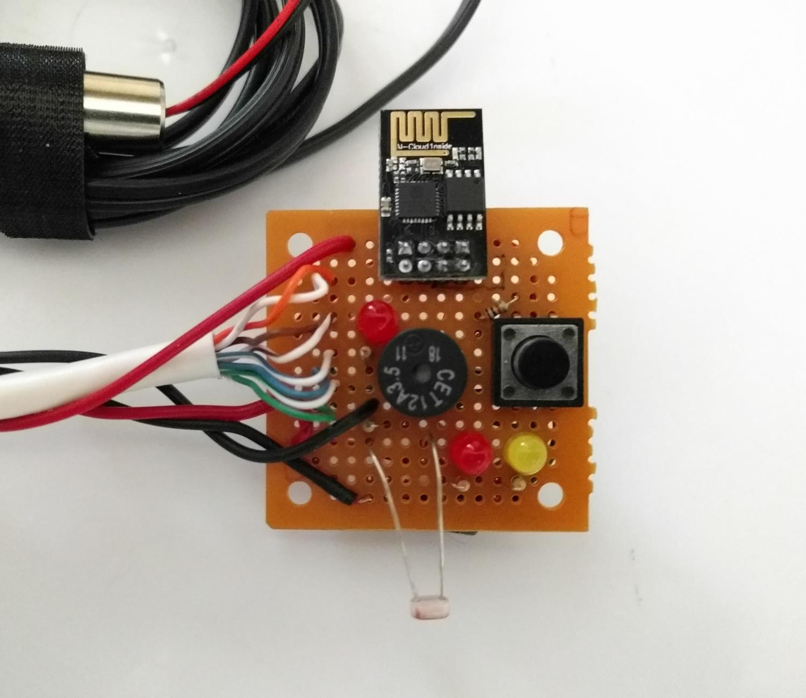
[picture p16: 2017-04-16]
docs/circuit_diagrams/module_WIFI/wifi_kit_details.jpg

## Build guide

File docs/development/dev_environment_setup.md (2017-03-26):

IDE / Dev Environment Setup Instructions
========================================

+ [Which IDE for Arduino Development?](#which-ide-for-arduino-development)
+ [IDE Setup Instructions](#ide-setup-instructions)
+ [Install Clang](#install-clang)
+ [Run a "Blink" program on your Arduino Uno](#run-a-blink-program-on-your-arduino-uno)
+ [(Optional) GitKraken Git GUI Client](#optional-gitkraken-git-gui-client)
+ [Clone the GitHub Repository](#clone-the-github-repository)

## Which IDE for Arduino Development?

We've chosen to use **[PlatformIO](http://platformio.org/)** as our IDE. We chose this above using the main [Arduino IDE](https://www.arduino.cc/en/Main/Software) for a number of reasons:

1. The Arduino IDE is quite _'barebones'_. It does not support nice features like auto-complete or code linting. PlatformIO does out of the box.
2. PlatformIO is built on the popular [Atom](https://atom.io/) text editor. The community behind Atom has _many_ plugins for various code formats, styles, themes, etc.1
3. Arduino IDE doesn't have Git Plugin support. Because PlatformIO is built on Atom, the ability to use a Git Plugin was just a few clicks away. _(Sure - we could have used Git from the commandline, but we wanted to simplify our workflow as much as possible.)_
4. We knew coming in that we would likely be pulling in additional libraries for this project. Arduino IDE doesn't manage those for you. PlatformIO does out of the box.
5. PlatformIO is not only an IDE but a 'framework' which can be integrated into other IDEs such as Eclipse, CLion, Visual Studio, Netbeans, VIM, Emacs, Codeanywhere, and several others. This appealed to us because it gave the ability for a PlatformIO project to be built, run, uploaded, etc. using many development platforms.
6. Both the Arduino IDE and PlatformIO were supported on multiple platforms and were relatively self-contained which we wanted.

Some other IDEs considered:

1. [Sloeber](http://eclipse.baeyens.it/index.shtml) _(Prepackaged, Eclipse-based IDE.)_
2. [CLion](https://www.jetbrains.com/clion/)
3. [Programino](http://www.programino.com/) _(Offers a pretty neat feature which displays your Arduino board's pinouts and specs right in the IDE)_

## IDE Setup Instructions

1. Ensure that a recent version of Python 2.X is installed
	* Most platforms, except [Windows](https://www.python.org/downloads/windows/), will likely have this preinstalled.
2. [Download](http://platformio.org/platformio-ide) the PlatformIO IDE for your platform
3. Run the installer. PlatformIO will install Atom then launch it.
	* Note - if you already have Atom installed it will launch the existing Atom instance you have installed and install itself as a plugin
4. Wait for installation to complete. When prompted, restart Atom.

## Install Clang
Clang is what PlatformIO uses for the Intelligent Code Autocompletion. It comes installed on some platforms but not on Windows or some flavors of Linux. Other platforms may also need to install it. You can find all the platform instructions [here](http://docs.platformio.org/en/latest/ide/atom.html#ide-atom-installation-clang).

1. Navigate to the (Clang Download)[http://llvm.org/releases/download.html] page.
2. Under the `Pre-Built` Binaries section, choose the (Clang for Windows (64-bit))[http://releases.llvm.org/3.9.1/LLVM-3.9.1-win64.exe] option to download it
3. Follow the install prompts. Make sure that you choose the `Add LLVM to the system PATH for all users` option while installing.
	* Note - if you see `Failed to find MSBuild toolsets directory` error in the installation console, please ignore it and press any key to close this window. PlatformIO IDE uses only Clang completion engine that should work after it without any problems.
4. You will need to restart PlatformIO / Atom if it was already running

## Run a "Blink" program on your Arduino Uno
This step will make sure that PlatformIO is full installed and configured properly. These are almost the exact steps provided by PlatformIO in their (quick start)[http://docs.platformio.org/en/latest/ide/atom.html#quick-start] guide. UIt also includes screenshots so if you are having difficulties with any of these steps refer to it to help you along.

1. From the PlatformIO 'Home' page...
2. Click the `+ New Project` button
3. Click the `Selected board` dropdown and choose Arduino --> Arduino Uno
4. Next to the `Choose the directory` dropdown click the `other` button to browse to a location where you want the code to reside
	* I would choose a temporary location as this will only be really run once to make sure everything is configured
5. Click the `Process` button
6. Wait for the "Installing platform: atm..." message to go away and for the new project to be created
7. Right-click on the `src` folder and choose `New file`
8. Enter `src\main.cpp` in the dialog box that appears
9. Hit your Enter key
	* Note - on Windows and some other platforms it is at this point that PlatformIO will recognize you don't have "Clang" installed if you didn't follow the install instructions above. If this happens, follow the `Install Clang` instructions above.
10. In main.cpp past in the following code:
	```cpp
	/**
	 * Blink
	 *
	 * Turns on an LED on for one second,
	 * then off for one second, repeatedly.
	 */
	#include "Arduino.h"

	#ifndef LED_BUILTIN
	#define LED_BUILTIN 13
	#endif

	void setup()
	{
	  // initialize LED digital pin as an output.
	  pinMode(LED_BUILTIN, OUTPUT);
	}

	void loop()
	{
	  // turn the LED on (HIGH is the voltage level)
	  digitalWrite(LED_BUILTIN, HIGH);

	  // wait for a second
	  delay(1000);

	  // turn the LED off by making the voltage LOW
	  digitalWrite(LED_BUILTIN, LOW);

	   // wait for a second
	  delay(1000);
	}
	```
11. Build the project by either clicking the `PlatformIO --> Build` menu option, clicking in the lower left on the `PlatformIO: Build` button, or clicking the `checkmark` icon on the left of the screen.
	* If prompted, click the `Save and build` option
12. You should see a console window appear. It will compile several things. Wait for this to complete.
13. Eventually you should see a `SUCCESS` message
14. Plug in your Arduino Uno
16. Upload the project by either clicking the `PlatformIO --> Upload` menu option or click the right-facing `arrow` icon on the left of the screen.
17. A console window will appear. It will do several things and then upload the code to your Arduino. On the Arduino you should see multiple LEDs light up when the program is being uploaded.
18. The LED on your Arduino board should turn on then off in 1-second intervals
	* Note - This "Blink" program comes preinstalled on many boards so it may start blinking right when you first plug it in. TO make sure you've uploaded a new program correctly I'd suggest changing the delay amounts to something other than 1-second each then reuploading it. This way you know for sure it is your code that is runnin on it.
19. Congratulations! You've hit a milestone - you've created your first PlatformIO application as well as run it on your Arduino! If you encountered any issues then they need to be address at this point before continuing on.

## (Optional) GitKraken Git GUI Client
If you would like to use a Git GUI Client I'd recommend **[GitKraken](https://www.gitkraken.com/)**. It is pretty much awesome!

There are other Git GUI clients out there such as [SmartGit](http://www.syntevo.com/smartgit/) or Github's own [GitHub Desktop](https://desktop.github.com/) which do a great job to help you interact with Git, but GitKraken just takes a different approach from these. The visuals, the drag-and-drop to commit, the overall interface just feel nice. No specific instructions are provided for any of these.

## Clone the GitHub Repository

1. From the command line...
2. Navigate to the directory where you would like the project to reside
3. Issue the following Git command:
	```
	git clone https://github.com/Lastrellik/Calico-Home-Security.git
	```
4. Launch PlatformIO
5. Click the "Open Project" button on the PlatformIO Home tab
6. Browse to the directory where you checked out the Repository
7. Click the Select Folder button1
8. Congratulation! You are now ready to begin development on the Calico Home Security System!

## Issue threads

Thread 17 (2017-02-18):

Refactor Components to have a shared Super class

Zeustopher, 2017-02-18:
There is duplicated code in each of the components for the following:
- Pin Number
- Constructor setting a pin number
- Getting the pin number
- Storing a componentType String
- getting the componentType

This suggests we need a shared class that all of the current components can extend from.

Call the base class "Component".

Lastrellik, 2017-02-19:
I've started on this. I just need to figure out the C++ syntax. The way you did the component classes is very foreign to me. @Zeustopher, do you have any resources on the format you were using, specifically the buzzer::buzzer() type of syntax?

Closed 2017-02-21.

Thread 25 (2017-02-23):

Create a Sequence Diagram / Flow Diagram for how base module will work

Zeustopher, 2017-02-23:
Create a basic [Sequence Diagram ](https://en.wikipedia.org/wiki/Sequence_diagram) or Flow Diagram for how the base module will function.

This should cover the User's interaction with turning on the unit, the unit going through its self testing, its configuration, its calibration, the User arming the system, then what happens when the laser line is broken, how the User disarms it, etc.

I recommend we use [UMLet](http://www.umlet.com/) for this diagram. It isn't the most friendly piece of software, and feels like you've gone back to the 1990's and using a piece of software designed back then, but it works well and is used by actually quite alot of people. Then we can include both the exported PNG as well as version control the actual UMLet diagram (they have the extension *.uxf and are basically an XML document).

Put the diagrams inside the docs directory.

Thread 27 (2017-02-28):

Basic IR module

sithboy, 2017-02-28:
Create wiring diagram
The IR module will be a remote method to arm and disarm Arduino base unit.

- Show a basic layout for the IR module
- Code arm " if pressed " into main.cpp
- Update documentation
- Stand-alone IR component for testing and implementation
- Check if IR module is present

sithboy, 2017-02-28:
Try and complete this by March 5th.

sithboy, 2017-04-19:
ir module for turret scrapped.

Closed 2017-04-19.

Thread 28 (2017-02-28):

Add detailed 'logging' statements

Zeustopher, 2017-02-28:
It would be nice to have detailed/comprehensive 'logging' statements which showed each step's start and end.

For example:
"Starting Component Testing"
"Testing LED........ PASS"
"Testing BUZZER....... PASS"
...
"Calibration Complete"
"Arming System"
"System Armed"
.......
"Line Tripped. Beginning Countdown..... 5.....4.....3.....2.....1...."
"Alarm Sounded"
.... etc etc etc etc

Since we don't really have a real 'log' file in the Arduino, this should all just be spit out on the Serial channel.

This should be configureable so that we can disable all 'log' statements. Perhaps make a variable called "debugging" and initially set it to true and then check that boolean's value before writing anything out to the log.

_(Future Idea: Perhaps could collect this output using a Raspberry Pi and actually persist it in a real log file?)_

Zeustopher, 2017-02-28:
@Boomstick105 - This was the idea I had that I was talking to you about. Feel free to pick this one up and work on it if you'd like.

Lastrellik, 2017-03-13:
The Serial.Print() commands seem to have somehow broken the code. I checked out the master branch and tried running it and it froze up in the middle of calibration. I tried for some time to try to fix it and couldn't get it to work. In [#39](https://github.com/Lastrellik/Calico-Home-Security/pull/39) I was resolved this by removing the various Serial.Print() commands throughout the code.

Although I could have the PI ignore the various Serial messages, I feel like it would cause more headache than benefit. I plan on implementing a logging function in the PI that will use Java's logger API to store it to a text file on the PI. This can be easily done by using the SerialComm::sendLogMessage(String message) from the Arduino and the PI will log those messages automatically. However, raw Serial traffic messes with the PI currently.

Outside of the PI, what would we want to log to anyway?

Zeustopher, 2017-03-13:
@Lastrellik - It looks like we were both working on fixing the issue at the same time. See my https://github.com/Lastrellik/Calico-Home-Security/pull/40 Just adding a tiny delay at the end of the method corrected the issue for me. Would you pull down that branch and see if it corrects it for you?

The downside of using the current SerialComm class is it seems to be _heavily_ designed towards communication with the PI. Serial debugging messages like these should be easily accessible to anyone by just hooking up the Serial Monitor in PlatformIO/Atom. I haven't (yet) gone through the entire class and used it yet so some of that statement of it being focused heavily towards PI communication is an assumption, but based on earlier commits I looked at and hearing you discuss the SHA1 stuff, it appears to be that way.

There is _huge_ value in logging statements scattered throughout code similar to what we have here. Then at a glance, when troubleshooting an issue, a person can hook up the unit via USB, launch the Serial Monitor, and see where the program is failing / what the sensor is reading / what is happening / etc.

What really should happen is these log statements should be wrapped with an if-check on the Properties::DEBUGGING_ACTIVE flag. If its on then it should go directly out to Serial. This is how I did it in my Wifi.cpp class.

So I'm of the opinion that, unless we can figure out how to do actual debugging with the Arduino and PlatformIO/Atom then we should keep the logging statements as-is-ish (with the refactor mentioned above to wrap them with the if check).

Zeustopher, 2017-03-25:
We're going in a somewhat different direction on this. See https://github.com/Lastrellik/Calico-Home-Security/blob/master/docs/development/logging.md for details. I'm going to close this issue and we can reopen others in the future if needed.

Closed 2017-03-25.

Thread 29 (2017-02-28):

MODULE - WiFi

Zeustopher, 2017-02-28:
We want to implement a WiFi module. The ultimate idea would be that you could remotely arm/disarm the system and get notified _(sms message? email? push notification of some sort?)_ when the alarm is triggered. The WiFi module itself will be an ESP8266.

I imagine this will need to come in several phases:
1. Get a manual proof-of-concept coded. This will be manually typing the "AT" commands and making sure they work.
2. Get a proof-of-concept coded where the Arduino sends the "AT" commands.
3. Add a wiring diagram and update all the documentation.
4. Implement some sort of notification. Maybe call a REST endpoint somewhere which triggers a message of some sort.
5. Hook in the notification to the alarm code.
6. Implement a proof-of-concept for the arduino receiving a remote command.
7. Implement a remote arm / disarm MVP (Minimum Viable Product). Hard coded http command to it or something. Maybe use Blynk?
8.Update documentation.

This order seems reasonable to me because it keeps a logical flow moving forward and adds one piece of functionality at a time.

Zeustopher, 2017-04-02:
There is still more work to do on it, but I think I'm going to call this particular issue done.

Closed 2017-04-02.

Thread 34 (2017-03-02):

No Disarm Functionality While Armed

Lastrellik, 2017-03-02:
While testing the alarm in class I found that we aren't able to disarm the alarm once it's been armed. I imagine a good way for us to do this is to make it so that the button on the board disarms the alarm if it's armed.

I'm actually going to assign this to @Boomstick105 because I'm interested in seeing his feedback on working with this code.

Lastrellik, 2017-03-19:
I went ahead and took care of this.

Closed 2017-03-19.

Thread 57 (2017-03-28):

Pi's SerialComm check for "matches("Arduino.*")" doesn't work on all platforms

Zeustopher, 2017-03-28:
I found that when I tried to run the Raspberry Pi app it would fail and give me the message `Arduino Uno Cannot Be Found` in the console. I found that this is happening in the `SerialComm` class of the Raspberry Pi app.

After debugging I found that this came down to how the comPort is being located. It is currently using ```.matches("Arduino.*")``` to locate the Arduino. However, on my machine (Windows 10) and with my board (Uno Rev. 2) it shows up as `USB Serial Device (COM3)`. It doesn't have the word `Arduino` in it anywhere.

I don't know the scope of this issue since I've only got one board and it is slightly older than some of the other boards (Rev. 3) that other group members have.

In order to correct the issue I had to add ```|| comPorts[i].getDescriptivePortName().matches("USB.*")``` to the if-check in order for it to pick up the board on my machine and have the app function properly.

The code causing this issue:
```java
private SerialPort getArduinoCommPort() {
  SerialPort[] comPorts = SerialPort.getCommPorts();
    for (int i = 0; i < comPorts.length; i++) {
      if (comPorts[i].getDescriptivePortName().matches("Arduino.*")) {
        return comPorts[i];
      }
    }
    throw new NoSuchElementException("Arduino Uno Cannot Be Found");
}
```

And with my modifications:
```java
private SerialPort getArduinoCommPort() {
  SerialPort[] comPorts = SerialPort.getCommPorts();
    for (int i = 0; i < comPorts.length; i++) {
      if (comPorts[i].getDescriptivePortName().matches("Arduino.*") || comPorts[i].getDescriptivePortName().matches("USB.*")) {
        return comPorts[i];
      }
    }
    throw new NoSuchElementException("Arduino Uno Cannot Be Found");
}
```

I didn't want to create a pull request for this without some discussion first because I don't know what the scope of the issue is. I'd like to see if @sithboy and @Boomstick105 can also run this java app and see what their boards show up like on their machines.

sithboy, 2017-03-28:
At class right now. Will give it a go this afternoon.
On Tue, Mar 28, 2017 at 8:40 AM Christopher Nash <notifications@github.com>
wrote:

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
--
Dave Tille

Lastrellik, 2017-03-28:
@Zeustopher The only concern I have is that it's possible that other devices will start with USB. I wonder if we should make the regular expression a little more specific.

Zeustopher, 2017-03-28:
Yeah - that would be fine with me. I had similar thoughts. I just don't know how best to expand the regex with only having two points of data. There could also be many other peripherals that match even a more specific one though since its description is _so_ vague.

Its possible that it is only my board too since I've got a little bit of an older one.

Lastrellik, 2017-03-28:
On the same note, the only other USB device that plugs into the PI would maybe be a webcam or possibly an external hard drive. I'm not sure what it's descriptive port name would be. For development, however, who knows what devices are going to be plugged into the developer's computer. I initially had it set up so that the developer had to select which port was the arduino, but that's not exactly automatic.

Lastrellik, 2017-04-16:
I think I got this to work with [#83](https://github.com/Lastrellik/Calico-Home-Security/pull/83), but it's a gamble if there are more than one serial devices plugged into the computer at once.

Closed 2017-04-30.

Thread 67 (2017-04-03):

Implement Unit Tests on Raspberry Pi Code

Lastrellik, 2017-04-03:
With my last [pull request](https://github.com/Lastrellik/Calico-Home-Security/pull/66) I created basic framework to begin implementing unit tests on the Raspberry Pi code. I think it makes sense to get full test coverage on the code and implement a test-driven development paradigm moving forward.

Lastrellik, 2017-04-13:
Oh yeah, this is done as well.

Closed 2017-04-13.

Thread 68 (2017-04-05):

Arduino Constantly Outputs to Serial

Lastrellik, 2017-04-05:
After creating my testing methods in the PI code I found that it started to behave weirdly... It kept trying to create a DataPacket and I thought that the Arduino wasn't supposed to be sending anything over Serial.

I Ran the Arduino code and looked at the Serial Monitor from within Platform.io and found that it sends data over the serial port even when the debugging and Raspberry Pi properties are set to false. This is due to missing (if Properties::MODULE_PI) checks before the serial write. It just floods the serial port with "-" symbols. For example:
````c++
void Alarm::alertFailedAction(){
  Serial.write(13102); // 13102 = Log, Debug, Alarm failed action
  _buzzer->soundNegativeTone();
  _redLED->flash(1000);
}
````
The above code should be turned into this:
````c++
void Alarm::alertFailedAction(){
  if(Properties::MODULE_PI) Serial.write(13102); // 13102 = Log, Debug, Alarm failed action
  _buzzer->soundNegativeTone();
  _redLED->flash(1000);
}
````
or this:
````c++
void Alarm::alertFailedAction(){
  if(Properties::DEBUGGING_ACTIVE) Serial.write(13102); // 13102 = Log, Debug, Alarm failed action
  _buzzer->soundNegativeTone();
  _redLED->flash(1000);
````

@Zeustopher, should we do MODULE_PI or DEBUGGING_ACTIVE for writing the serial commands?

@Boomstick105 can you fix this one? I spent some time trying to find what the culprit is and I couldn't. Weirdly enough, the Raspberry Pi still worked, it wasn't until I modified the code to throw exceptions on illegal inputs that I noticed that it was constantly throwing illegal inputs. However, all logging functionality and what I'm trying to work on next will not work until this is fixed.

Boomstick105, 2017-04-05:
Is it those few lines in particular throwing the errors, guess after
reading it i
I'm still a little loss, but I'm reading this after just barely waking up,
I can also clarify it later I  class with you.

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

Boomstick105, 2017-04-05:
I see it after reading it a couple times, it just all looked very similar
reading it at first, I'll take a look at the code. Is this going you need a
full branch and pull request to change it or would I be able to submit the
changes from a past one?

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

Zeustopher, 2017-04-05:
I'm on the fence on which it should be wrapped with (MODULE_PI or DEBUGGING_ACTIVE). I think for now lets do `if(Properties::MODULE_PI)`.

Really, every one of the Serial.write commands should have that if-check in front of it.

@Boomstick105 - You'll need to do the changes on a branch off master and then do a pull request.

Lastrellik, 2017-04-05:
@Boomstick105 remember to checkout the master branch and then do a git pull before creating this second branch. It would also be helpful to load the code onto the Arduino and let it run with the Serial Monitor running. If MODULE_PI is set to false, nothing should print over serial.

Lastrellik, 2017-04-13:
This has been resolved.

Closed 2017-04-13.

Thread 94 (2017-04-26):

Alarm arming issue

Lastrellik, 2017-04-26:
If the alarm gets calibrated and then the laser points away from the photoresistor, the alarm will arm, but then immediately trip instead of failing to arm in the first place.

We need to throw something in the isReadyToArm() function in the Alarm class that checks to see if the laser is pointing correctly. Since the laser is off before we actually arm it, I think we'll need a method that turns the laser on, checks to see if the photoresistor reading changed significantly, and fail to arm if it doesn't. This prevents false positives. The laser and photoresistor respond pretty quickly, so I bet we can run that check in 10 milliseconds or less.

Lastrellik, 2017-04-29:
Fixed with [this](https://github.com/Lastrellik/Calico-Home-Security/pull/98) pull request.

Closed 2017-04-29.

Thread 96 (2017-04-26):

Packet Byte Misalignment

Lastrellik, 2017-04-26:
Sometimes the PI module freezes up on startup because the packet message isn't in the message table. I suspect that it's because there is existing data in the buffer on the Arduino when I power up the program on the PI, but it doesn't happen 100% of the time.

It throws an exception "[three numbers] doesn't represent a packet type" but the program keeps running. A quick fix would be for this exception to kill the program instead of just malfunctioning. We should do this, but this won't fix the root cause of the issue. I suspect we'll have to do a buffer flush or something similar to that.

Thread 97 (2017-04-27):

Remove External Dependencies (Arduino) From Unit Tests

Zeustopher, 2017-04-27:
See https://github.com/Lastrellik/Calico-Home-Security/pull/69 for where this was originally identified.

For "_Unit Testing_" you don't want to rely on an outside dependency like exists in the `SerialInputListenerTest.java` test class. You wouldn't want to have the actual Arduino respond to a ping. You would instead want to "mock" the Arduino.

For "_Acceptance Testing_" (_or possibly "Integration Testing" or "System Testing"_) - http://softwaretestingfundamentals.com/acceptance-testing/ you want want to test the 'interaction ' or 'integration' with external dependencies. This helps check to make sure the 'contract' between the two things is still correct. Those tests are generally written in a test file of their own and run separately from Unit Tests. But for Unit Tests you wouldn't want to deal with external dependencies.

To accomplish the test you look like you are wanting to do here there are multiple 'mocking' frameworks out there that will let you accomplish basically what you're wanting to do. In essence it is like making a "fake arduino" that you'd "call" and get a packet response back from.

One such mocking framework is [Mockito](http://site.mockito.org/) (_another I've heard a bunch about is called [EasyMock](http://easymock.org) though I've never used it myself_). With it you'd end up doing something similar to declaring a mock for the sender and then do a line something like ```when(mockedSerialSender.isPacketAvailable()).thenReturn(true);``` (Obviously I haven't looked in detail at what the actual calls would be but thats just an example). Then you would make the call and move forward with whatever test you would want to accomplish. Reading over the front page of Mockito's website will help make it more clear than the example I showed here.

I also believe I saw it noted in another pull request or a comment in the code that the same sort of dependency occurs on the webcam (or possibly the touchscreen though I think its the webcam).

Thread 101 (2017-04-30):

Alarm calibration with GUI

Lastrellik, 2017-04-30:
I had it set up so that the Arduino won't automatically attempt to calibrate the alarm on startup when Properties::Module_Pi is true because I wanted to control that from the PI. However, I never actually threw that feature in. This still needs to be added.

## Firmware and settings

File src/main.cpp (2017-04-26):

/**
  Calico Home Security System, ComponentTester.cpp
  Purpose: Main class that manages looping of other classes and manages
    sequentially checks of certain conditions.

  @author Christopher Nash, Jason Bruderer, David Tille, Tyler Jacobs
*/
#include "Arduino.h"

#include "LED.h"
#include "Alarm.h"
#include "Photoresistor.h"
#include "Buzzer.h"
#include "Button.h"
#include "ComponentTester.h"
#include "Laser.h"
#include "Properties.h"
#include "module_PI/Arduino_Uno/CommandListener.h"

Alarm* alarm;
CommandListener* commandListener;

long timeAlarmHasBeenTrippedInMillis = 0;

#include "module_WIFI/WifiModule.h"
WifiModule* wifiModule;

#include "module_TURRET/TurretMASTER.h"
TurretMASTER* turretMASTER;


/**
  Sets up the intial classes to be used like Alarm and Wifi
*/
void setup() {
  Serial.begin(Properties::BAUD_RATE);
  alarm = new Alarm();

  if(Properties::LASER_AIMING_MODE){
    alarm->toggleLaser();
    while(not alarm->isButtonPressed()) {
      // Loop here until the button is pressed
    }
    alarm->toggleLaser();
  }

  if(not Properties::MODULE_PI) alarm->testBoardComponents();
  commandListener = new CommandListener(alarm);
  if(not Properties::MODULE_PI) alarm->calibrate();

  if (Properties::MODULE_WIFI) {
    alarm->alertWaitingAction(); // Let the user know that we're preparing to connect
    wifiModule = new WifiModule();
    wifiModule->initialize();
    if(wifiModule->isInitialized()) {
      alarm->alertSuccessfulAction(); // Let the user know that everything is good
    } else {
      alarm->alertFailedAction();
      alarm->alertFailedAction(); // Let the user know that something didn't go right
      alarm->alertFailedAction();
    }
  }

  if (Properties::MODULE_TURRET) {
    turretMASTER = new TurretMASTER();
  }
}

/**
  Looping command for active listening or what is happening on the Arduino.
    Listens to see if the alarm has been trigged, calibrated, or armed.
*/
void loop(){
  commandListener->executeCommandIfAvailable();
  if(not alarm->isArmed()){
    if(alarm->isButtonPressed() && alarm->isCalibrated()){
      alarm->arm();
    }
  } else {
    if(alarm->isLaserBeamBroken() && not alarm->isTriggered() && not alarm->isTripped()){
      alarm->trip();
    }
  }

  if(not alarm->isCalibrated()){
    if(alarm->isButtonPressed()){
      alarm->calibrate();
    }
  }

  if(alarm->isTriggered()){
    alarm->soundOneAlarmCycle();
  }

  if((alarm->isTriggered() || alarm->isTripped()) && alarm->isButtonPressed()){
    alarm->disarm();
    if (Properties::MODULE_TURRET) {
      turretMASTER->resetStatus();
    }
  }

  if(not alarm->isTripped() && not alarm->isTriggered()){
    timeAlarmHasBeenTrippedInMillis = 0;
  }

  if(alarm->isArmed() && alarm->isButtonPressed()){
    alarm->disarm();
    if (Properties::MODULE_TURRET) {
      turretMASTER->resetStatus();
    }
  }

  if(alarm->isTripped()){
    long startTime = millis();
    alarm->alertWaitingAction();
    timeAlarmHasBeenTrippedInMillis += millis() - startTime;//Seconds it takes for the
    if(timeAlarmHasBeenTrippedInMillis >= Properties::ALARM_TRIPPED_TO_TRIGGERED_MILLIS){
      alarm->trigger();

      if (Properties::MODULE_WIFI && wifiModule->isInitialized()) {
        wifiModule->sendNotification(); // TODO: This is blocking. See https://github.com/Lastrellik/Calico-Home-Security/issues/62
      }

      if (Properties::MODULE_TURRET) {
        turretMASTER->sendTransmission(Properties::TURRET_SLAVE_NUMBER, Properties::TURRET_COMMAND);
      }
    }
  }
}

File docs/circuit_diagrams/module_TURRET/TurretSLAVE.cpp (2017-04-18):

#include "Arduino.h"
#include <Wire.h>
#include <Servo.h>

int ic2SlaveNumber = 9; // Configure this value to be the number you will communicate with via the Master

int commandCode = 0;

///// PAN Servo
Servo servopan;
int panPin = 3;
int position_P = 0;

///// TILT Servo
Servo servotilt;
int tiltPin = 4;
int position_T = 0;

///// GUN
int gun = 7;

void receiveEvent(int bytes) {
  commandCode = Wire.read();    // read one int from the I2C
}

void beginTurretSequence() {
  for (position_P = 0; position_P <= 120; position_P += 1);
  for (position_T = 60; position_T <= 100; position_T += 1) {
    servopan.write(position_P);
    servotilt.write(position_T);
    delay(10);
  }

  digitalWrite(gun,HIGH);
  delay (500);
  digitalWrite(gun,LOW);

  for (position_T = 120; position_T >= 100; position_T -= 1);
  for (position_P = 120; position_P >= 0; position_P -= 1) {
    servopan.write(position_P);
    servotilt.write(position_T);
    delay(10);
  }

  digitalWrite(gun,HIGH);
  delay (500);
  digitalWrite(gun,LOW);

  commandCode = 0;
}

void blinkLED_Fast() {
  for (int i = 0; i < 5; i++) {
    digitalWrite(LED_BUILTIN, HIGH);
    delay(200);
    digitalWrite(LED_BUILTIN, LOW);
    delay(200);
  }

}

void blinkLED_Slow() {
  for (int i=0; i < 5; i++) {
    digitalWrite(LED_BUILTIN, HIGH);
    delay(800);
    digitalWrite(LED_BUILTIN, LOW);
    delay(800);
  }
}

void setup() {
  Serial.begin(9600);
  pinMode (LED_BUILTIN, OUTPUT);
  servopan.attach(panPin);
  servotilt.attach(tiltPin);
  pinMode(gun, OUTPUT);

  Wire.begin(ic2SlaveNumber);     // Start the I2C Bus as Slave
  Wire.onReceive(receiveEvent);   // Attach a function to trigger when something is received.
}

void loop() {
  if (commandCode == 0) {
    blinkLED_Fast();
  }

  if (commandCode == 3) {
    blinkLED_Slow();
  }

  if (commandCode == 9) {
    beginTurretSequence();
  }
}

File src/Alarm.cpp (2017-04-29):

/**
  Calico Home Security System, Alarm.cpp
  Purpose: Alarm creaties an alarm ojbect, arms it, disarms it, and calibrates the paramaters
  for the alarm object

  @author Christopher Nash, Jason Bruderer, David Tille, Tyler Jacobs

*/
#include "Arduino.h"
#include "Component.h"
#include "LED.h"
#include "Buzzer.h"
#include "Laser.h"
#include "Photoresistor.h"
#include "Button.h"
#include "Alarm.h"
#include "ComponentTester.h"

/**
  Base contructor that writes that the Alarm Object has been created
*/
Alarm::Alarm(){
if(Properties::MODULE_PI)  Serial.write("13100"); // 13100 = Log, Debug, Alarm object successfully created
}

/**
  Takes in the base calibration of the light level using the
    determineBasePhotoresistorReading function and alerts of failed action
      if alertFailedAction and return isCalibrated as false, else it returns
      isCalibrated as true.
    @param isCalibrated is set to true or false
*/
void Alarm::calibrate(){
  determineBasePhotoresistorReading();
  if(_photoR->takeReading() - _threshold < _baseReading){
    alertFailedAction();
    _isCalibrated = false;
  } else {
    alertSuccessfulAction();
    if(Properties::MODULE_PI)  Serial.write("13106"); // 13106 = Log, Debug, Alarm succesful calibration
    _isCalibrated = true;
  }
  _laser->off();
}
/**
  Creates a ComponentTester object that makes sure that all components are
    running
*/
void Alarm::testBoardComponents(){
  if (isArmed()) disarm();
  ComponentTester tester(_greenLED);
  tester.testPin();
  tester.testComponent(_redLED);
  tester.testComponent(_alarmLED);
  tester.testComponent(_photoR);
  tester.testComponent(_buzzer);
  tester.testComponent(_laser);
  //tester.testComponent(_armButton);

}

/**
  Determines a base of the photorsistor at normal light levels and then
    determines the value of the photorsistor when the laser is on it.
  @param avgReading a base for photorsistor at normal light, taken over time,
    determine the average light level of the room.
  @param numOfReadings hardcoded number used a for loop to help determines the
    base reading.
*/
void Alarm::determineBasePhotoresistorReading(){
  _laser->off();
  int avgReading = 0;
  int numOfReadings = 15;
  for(int i = 0; i < numOfReadings; i++){
    avgReading += _photoR->takeReading();
    _greenLED->flash();
  }
  _baseReading = avgReading / numOfReadings;
  if(Properties::MODULE_PI) Serial.write("13101"); // 13101 = Log, Debug, Alarm base photorsistor reading determined
  _laser->on();
}

/**
  Makes the buzzer produce the Negative tone
*/
void Alarm::alertFailedAction(){
  if(Properties::MODULE_PI) Serial.write("13102"); // 13102 = Log, Debug, Alarm failed action
  _buzzer->soundNegativeTone();
  _redLED->flash(1000);
}

/**
  Makes the buzzer produce the Affirmative tone
*/
void Alarm::alertSuccessfulAction(){
  if(Properties::MODULE_PI) Serial.write("13103"); // 13103 = Log, Debug, Alarm successful action
  _buzzer->soundAffirmativeTone();
  _greenLED->flash(1000);
}

/**
  Make an alert sound with lights to indicate the alarm is waiting.
*/
void Alarm::alertWaitingAction(){
  _redLED->flash(1000);
  _buzzer->soundTone(600, 300);
  _greenLED->flash(1000);
  _buzzer->soundTone(600, 300);
  _redLED->flash(1000);
}

/**
  Turns the LASER on and if it fails isReadyToArm turns it back off to as it the
    Alarm class needs to be calibrated again and leaves it on and sets isArmed
    to true and the _alarmLED to be on.
  @param _laser turns it on or keeps it off if calibration failed
  @param _alarmLED if alertSuccessfulAction is turned on
  @param _isArmed is alertSuccessfulAction is set to true
*/
void Alarm::arm(){
  if(Properties::MODULE_PI) Serial.write("13107"); // 13107 = Log, Debug, Alarm has begun arming
  _laser->on();
  if (!this->isReadyToArm()){
   Serial.write("13104"); // 13104 = Log, Debug, Alarm failed to arm
   this->alertFailedAction();
   if(!this->isArmed()) _laser->off();
 } else {
   this->alertSuccessfulAction();
    Serial.write("13105"); // 13105 = Log, Debug, Alarm successfully armed
   _alarmLED->on();
   _isArmed = true;
 }
}

/**
  @return returns true if the isArmed is not armed and isCalibrated is
    calibrated, and isTripped and isTriggered are not activated
*/
bool Alarm::isReadyToArm(){
  _laser->on();
  return(!this->isArmed()
      && this->isCalibrated()
      && !this->isTripped()
      && !this->isTriggered()
      && !this->isLaserBeamBroken());
}

/**
  Getter for the param _isArmed
*/
bool Alarm::isArmed(){
  return _isArmed;
}

bool Alarm::isLaserBeamBroken(){
  return (_photoR->takeReading() - 100 < _baseReading);
}

/**
  Getter for the param _isTripped
*/
bool Alarm::isTripped(){
  return _isTripped;
}

/**
  Sets the alarm to be triggered
  @param sets _isTriggered to be true
  @param sets _isSilenced to be false
  @param sets _isTripped to be false //Except these aren't parameters.
*/
void Alarm::trigger(){
  if(Properties::MODULE_PI) Serial.write("13108"); // 13108 = Log, Debug, Alarm has been triggered
  _isTriggered = true;
  _isSilenced = false;
  _isTripped = false;
}

/**
  Sets the alarm to be tripped
*/
void Alarm::trip(){
  if(Properties::MODULE_PI) Serial.write("13112"); // 13112 = Log, Debug, Alarm has been tripped
  _isTripped = true;
  _laser->off();
}

void Alarm::toggleLaser(){
  if(not _isCalibrated) _laser->toggle();
  if(Properties::MODULE_PI) Serial.write("13353"); // 13353 = Log, Debug, Laser has been toggled
}

/**
  If _isSilenced is not set soundAlarmHighTone and soundAlarmLowTone are used
    to set tone high and low, also tells _redLED and _alarmLED to flash
*/
void Alarm::soundOneAlarmCycle(){
  if (not this->_isSilenced) _buzzer->soundAlarmHighTone();
  _redLED->flash(300);
  if (not this->_isSilenced) _buzzer->soundAlarmLowTone();
  _alarmLED->flash(300);
}

/**
  Disarms the alarm and sets the calibration to false to resetCalibration
  @param _isCalibrated is set to false
*/
void Alarm::resetCalibration(){
  if(Properties::MODULE_PI) Serial.write("13109"); // 13109 = Log, Debug, Alarm calibration is being reset
  disarm();
  _isCalibrated = false;
}

/**
  @return _isTriggered getter
*/
bool Alarm::isTriggered(){
  return _isTriggered;
}

/**
  Used to disarm the alarm
  @param _isTriggered is set to false
  @param _isArmed is set to false
  @param _alarmLED is turned off
  @param _isSilenced is set to false
  @param _laser is turned off
*/
void Alarm::disarm(){
  this->alertSuccessfulAction();
  _isTriggered = false;
  _isTripped = false;
  _isArmed = false;
  _alarmLED->off();
  _isSilenced = false;
  _laser->off();
  Serial.write("13110"); // 13110 = Log, Debug, Alarm is being disarmed
}

/**
  Silences the alarm by setting _isSilenced to true
*/
void Alarm::silence(){
  _isSilenced = true;
  Serial.write("13111"); // 13111 = Log, Debug, Alarm is being silenced
}

/**
  @return getter for _isCalibrated
*/
bool Alarm::isCalibrated(){
  return _isCalibrated;
}
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

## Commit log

2017-01-26 Fixed Image In Readme
    Apparently Github won't render SVG images. I've switched it to the PNG version. It will probably show up a little too big, but it is at least a good start.
2017-01-26 Rotated Image
    I rotated the Laser Pointer to be horizontal instead of at an angle. In terms of using it in the Github repo this will probably look a little nicer. It can be tweaked further in the future.
    Also tweaked the subtitle below the image.
2017-01-30 Added (most of) a section on running a "Blink" program on your Arduino
    In order to make sure everyone's environment is set up properly, we need to have the simple Arduino-style "Hello World" program run on everyone's Arduino. This will hopefully help mitigate any issues that we have in configuring our IDEs on our various systems.
2017-01-30 Added some sample diagrams
    I added a few sample diagrams to the repository. As we come up with wiring, etc. for the project we can use the application called "Fritzing" to make both Wiring and Schematic diagrams.
    [base_wiring.fzz]
2017-02-02 Added a basic main.cpp
    I just grabbed the 'guts' of the Blink program and threw them in here for now. It just gives us a jumpstart.
    - Also added that we are going to want a buzzer as part of our 'base' hardware.
    [main.cpp]
2017-02-04 Extensive Documentation Refactor
    I've reorganized alot of the documentation. I think in the long run this organization will help keep things from getting too much in a single folder.
    - Create Modules directories and readme files for each of the modules we've identified so far
    - Moved the IDE / Dev Environment Setup Instructions to a file of thier own then linked to it on the main readme.
    -
    [base_wiring.fzz]
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2017-02-04 Added Base Module Wiring Diagram
    I've created the Base Module Wiring Diagram.
    I intentionally tried to keep everything on one half of the board as much as possible so that we can use the other half for future modules. I tried to also limit the pins being used to the pins in on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
    (_This was based off the wiring diagram found here: http://keithkay.com/2013/03/03/arduino-self-calibrating-laser-trip-wire/_)
    [base_wiring.fzz]
2017-02-10 Added "Mini" Module
    I was thinking that it might be nice to provide a "Mini" module which operates on only the bare essentials of a single resistor, the photoresistor, and uses the built in LED. All the details aren't flushed out yet, but it was a good starting point.
    I also added a table to the modules' readme. I think there might be some modules that won't play nicely together or are redundant. Thhis will give us a way of documenting that.
    [mini_wiring.fzz]
2017-02-18 Added Component Classses
    Added the following classes to the project:
    - LED
    - PhotoResistor
    - Buzzer
    Changed main.cpp to use the new classes.
    Note for future refactor potential:
    - Instead of passing in the pin and the string to the tester we could pass in the component itself then have the tester pull out the type from the object passed in and do the log that way.
    - There is duplicated code in these classes for getting pin, componentType, etc. This suggests we should make a super-class for these classes. Possibly call it "Component". Then refactor these classes to make them subclasses of that class.
    [Buzzer.cpp, ComponentTester.cpp, LED.cpp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]
2017-02-18 Added Button Class
    I realized that we also have a Button component in our base module so I wanted to get a class made for that. I also added a check in main.cpp which checks if it is pressed and sounds a tone on the buzzer if it is.
    Also, I added a few methods to the Buzzer class so that you can manually control it instead of just specifying an amount of time to sound it for. If you use the method without the millisOn then it will just indefinately sound until you call the stopTone() method.
    [Button.cpp, Buzzer.cpp, main.cpp]
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2017-02-20 Add Laser to Base Diagram
    [base_wiring.fzz]
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2017-02-20 Add base file for the wiring diagram
    [base_wiring.fzz]
2017-02-22 Fix Laser Toggle Error
    [Laser.cpp]
2017-02-23 Corrected the Photoresistor's Name
    I originally named the file "PhotoResistor.cpp" but then I've referenced it as "Photoresistor.cpp" (note the "R" vs. "r" in resistor).
    On some platforms / using some compilers it handled this difference just fine. On some it blows chunks...
    This change renames the files so that this won't be any issue.
    [Photoresistor.cpp]
2017-02-23 Added a testComponent() method
    I've added a method which collapses both the "set" and the "test" methods into a single call. This will help keep our testBoardComponents() method a little shorter.
    Note - I left the original pattern for the constructor and the testPin() because we haven't defined a no-argument constructor yet. This would be another good refactor to do.
    - Also fixed a small typo
    [ComponentTester.cpp, main.cpp]
2017-03-01 Added .fzz, png and Readme for IR testing
    [Arduino IR output tester.fzz]
2017-03-03 Initial Documentation for Wifi Module
    This is still VERY WIP, but this is a start. This goes over some of the setup things you have to do in order to get the ESP8266 reaady to be used by the arduino.
    [wifi_wiring.fzz]
2017-03-09 Serial Print Line added to debug components when turning on and off
2017-03-13 Fix Broken Base and Implement Properties
    [Alarm.cpp, Button.cpp, Buzzer.cpp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]
2017-03-13 Corrected a 'race' condition
    I noticed that most of the time I would launch the program it would freeze during the initialization of the components. It would successfully initialize some of them and then freeze. I'm not sure where the issue is coming into play, but ading this very small delay fixes the problem. This seems to suggest that there is some sort of 'race' condition hidden in there somewhere. For such an easy fix/workaround it probably isn't worth any further investment into figuring out why.
    (Also fixed some formatting of the println(). )
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2017-03-14 Reverted removal of debug logging statements
    Reverted the changes made on 3f32aca390 to remove the debug logging statements.
    The next commit will be wrapping these with an if-check on whether the debug flag is enabled or not.
    [Alarm.cpp, Button.cpp, Buzzer.cpp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]
2017-03-14 Added check for DEBUGGING_ACTIVE before debug log statements
    We only want to send a bunch of debug logging statements if it is configured in Properties.cpp to be turned on. This change adds checks before each print statement to see whether it is enabled and only log if it is.
    It also adds a reference to the Properties.h file to those classes which didn't have it yet (even if they aren't currently debug logging anything).
    Note that *Debug Logging* is now *disabled by default*. The assumption here is that in a 'production' install, it is assumed that you don't need that constant stream of data happening and would only want to turn that on manually when you need to troubleshoot a device. Hav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
    [Alarm.cpp, Button.cpp, Buzzer.cpp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]
2017-03-14 Fixes based on review comments
    - Corrected an issue where c++ won't allow you to concatenate to sets of strings together without explicitly making one a String object. (_Why, c++?! Why?!_)
    - Surrounded some additional log statements with a check for whether the Pi Module is installed.
    [ComponentTester.cpp, main.cpp]
2017-03-14 Refactor Enum, Spelling Errors and Naming Conventions
    [main.cpp]
2017-03-15 Initial Turret Module Work
    This commit is @sithboy's that got misplaced onto an old branch.
    Contains an initial wiring diagram, updated readme file, and some initial code work.
2017-03-19 Add Logger and Stop Crashing
    [Alarm.cpp, Button.cpp, ComponentTester.cpp]
2017-03-23 Add Logging Documentation
    We decided that we need to change the way we are logging these. We discussed as a group a Logging & Command Message scheme we could start to use. This commit adds the documenation around that scheme 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
    At this point, none of this documentation has been implemented. We wanted the documenation in place before we started the refactor.
    Note - the values currently in the `Details` column of the table are just placeholders and will be updated with actual values as we perform the refactor.
2017-03-24 Add Defn. of Execute Commands and added Comment Convention
    I've added the definition for the 4 commands currently defined in the Ardunino's code to handle.
    I also added a Comment Convention that we should follow as we start working on the refactor for the logging, etc. Following this will help save a little time when a developer is lookng at the code to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
2017-03-25 Adopt Correct DataPacket Scheme and Improve Alarm
    [Alarm.cpp]
2017-03-25 Fix Laser And Listener Bug
    [Alarm.cpp]
2017-03-25 Fix Alarm Trigger on Double Arm Bug
    [Alarm.cpp]
2017-03-25 Fix false trigger bug in testBoardComponents
    [Alarm.cpp]
2017-03-26 Random Readme and Properties Documentation
    These are just various changes to the README files throughout the project as well as the addition of a few more Properties for the different Modules currently in the works.
    This commit should make no difference in terms of code functionality.
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2017-03-28 Changed from "Chris Nash" to "Christopher Nash"
    In print, etc. I generally use my full first name. This change just modifies the comments on many of the files to be `Christopher Nash` instead of `Chris Nash`. This also makes it consistent with the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
    There are NO actual code changes in this commit. Only comment changes.
2017-03-30 Wifi Module Refactor
    This change contains several items related to the Wifi Module.
    The first is the addition of the `lib_deps` section in the `platformio.ini` file. This uses PlatformIO's [Library management system](http://platformio.org/lib) to pull in the required `WiFiEsp` library.
    The next main refactor was renaming from `Wifi` to `WifiModule`. I had to do this as the WifiEsp library had a constant named Wifi which caused some compile and runtime issues. The quick-win was just renaming our file instead of working around it.
    The final refactor was in the wifi code itself. I cleaned out ALOT of the initial code I had done and replaced it with code utilizing the new WiFiEsp library. For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
    [WifiModule.cpp, main.cpp]
2017-03-31 Fixed bug causing Wifi Module not to function
    After hours of poking around it all came down to one little thing - I had forgot to start the communication of the esp8266 SoftwareSerial... /facepalm
    This is now functioning! The next commit will include some cleanup and hooking it up to actually trigger the notification when the alarm is triggered.
    [WifiModule.cpp]
2017-04-03 Added an idea about a Web Application
    I had another idea as I was thinking about it that having a web application to arm/disarm/see the status of the alarm would be reeally cool. Its also very in line with the way IoT is happening right 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
2017-04-08 Made wifi setup sound a 'waiting' tone on the alarm
    This change make a 'waiting' sound trigger before the wifi module connects to wirless and a 'success' sound trigger when it successfully connects.
    While debugging / working on my wifi module I realized that after the alarm goes through its normal setup procesures it turns control over to the wifi module to do its thing. It was difficult to know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
    Unfortunately, once I hand over control to the ESP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
2017-04-08 Updates with if statements to prevent constant output of serial messages, has not been tested yet, just submitting code
    [Alarm.cpp, Button.cpp, Buzzer.cpp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]
2017-04-10 Added if statements
    Updated to serial outputs with if statements to prevent constant writing
    [Alarm.cpp, Button.cpp]
2017-04-10 Fix Serial Flood Bug
    [Alarm.cpp, Button.cpp, ComponentTester.cpp]
2017-04-11 Update to the GUI
    Fixed the add user panel, able to add and delete without having to hit the delete button mutliple times.
    Add true and false states to help manage the state of items selected and users create.
    Auto clears after creating a user and is able to use all letters now.
2017-04-11 Switch to Command Line Arguments for Credential System and Fix Minor Errors
2017-04-11 Switch to Command Line Arguments for Credential System and Fix Minor Errors
    modified: src/module_PI/Raspberry_PI/JUnitTests/EmailNotifierTest.java
    modified: src/module_PI/Raspberry_PI/main/EmailNotifier.java
    modified: src/module_PI/Raspberry_PI/main/PiApp.java
2017-04-12 Repair Serial.write byte array bug
    [Alarm.cpp, Button.cpp, Buzzer.cpp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]
2017-04-14 Some improvements to the new Maven pom file
    This change adds some minor changes to the new Maven pom.xml file.
    - Specifies the Java version to use when compiling the code. It was unspecified but now lists Java 8 (1.8) as the copile target.
    - Adds the junit dependency
    - Specifies where the source directory is for the Raspberry Pi module. Before it was getting everything in the `src/` directory, including the c++ files, and including them in the `target` directory 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
    It is likely that the IDE you were using while developing (Eclipse?) defaulted to including the junit dependency automatically and sortof bypassing Maven. Same thing goes for the Java version. These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
2017-04-15 Resolve indentation errors and extra Camera declaration
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2017-04-17 Add trip and wait functionality to Arduino and resolve photoresistor flood issue
    [Alarm.cpp, LED.cpp, Photoresistor.cpp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]
2017-04-17 Added Turret Module
    This is the start of the Turret Module. This code is still current UNTESTED as I can't get my old Arduino to work with the I2C protocol correctly.
    There is more work needed for this module in both the code and to documentation that will need to come in future commits.
    The code does build and shouldn't cause any disruptions.
    [main.cpp]
2017-04-17 Fixed bug where timeAlarmHasBeenTrippedInMillis doesn't reset if disarmed from gui
    [main.cpp]
2017-04-17 Added Turret Diagrams
    [turret_wiring.fzz]
2017-04-17 Updated Diagrams to be more vertical
    The previous way I had the diagram designed was much more horizontal which didn't look great in Github. This change makes it so that it is now more vertical which will look better.
    [turret_wiring.fzz]
2017-04-18 Finalized the Initial Turret Module Code
    The I2C between the two devices works as expected!
    I'm not able to test the turret code so this will have to now go to someone who has the turret components available to them.
2017-04-25 Backslashes not compatible with Linux
    [main.cpp]
2017-04-26 Added Laser Aiming Mode & Moved Trip Time to Properties
    - I moved the amount of time between Tripped and Triggered to be in the Properties files. This way it is easier to configure with all of the other application settings.
    - It was very useful while setting up our demonstration for the Raspberry Pi to be able to turn on the laser and just leave it on. I implemented a similar mechanism for the base module so you can flip a flag in the Properties file and it will toggle the laser on and leave it on until you press the button. This will help in aiming.
    [main.cpp]
2017-04-26 Improved Wifi Connect Flow
    I wasn't handling the case where I couldn't connect to wireless. This change allows a configurable number of retry attempts before returning, alerting the user that something is wrong, then continuing with the rest of the alarm functionality.
    [WifiModule.cpp, main.cpp]
2017-04-28 Resolve laser bug
2017-04-30 Added Business Cards Template
    In case they ever wnat to be used again, I'm adding the Business Cards that I made for us to hand out at the Programming JAM to the GitHub Repository in /docs/promotional/ directory.
    - I also tacked on a few changes to the Wifi Module's README. I've had these changes for a little while but just didn't want to make a Pull Request all by itself for something so small to add them...
